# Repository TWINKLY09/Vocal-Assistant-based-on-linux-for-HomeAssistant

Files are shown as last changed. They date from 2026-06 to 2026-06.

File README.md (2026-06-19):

# 🎙️ Voice Assistant — Open Hardware

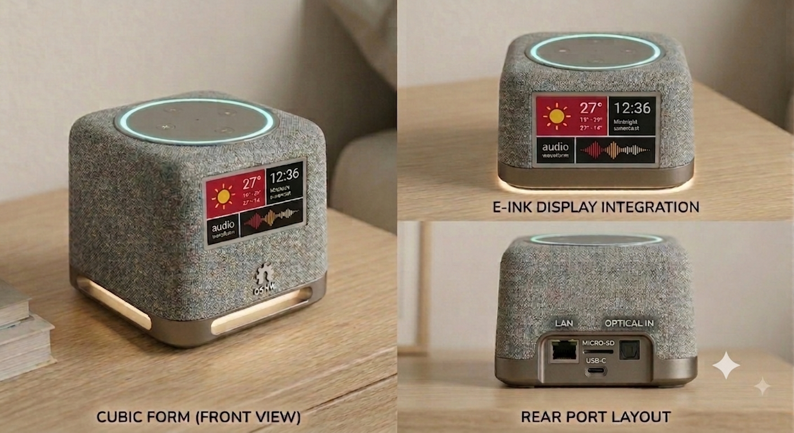
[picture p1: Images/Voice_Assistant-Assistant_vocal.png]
Voice Assistant - Assistant vocal


This image has been generated by gemini

> **⚠️ Work in progress / En cours de développement**
> 
> Hardware is being validated, software is not yet functional end-to-end.
> **3D enclosure files are not yet available** — mechanical design is still in progress.
>
> Le hardware est en cours de validation, le software n'est pas encore fonctionnel de bout en bout.
> **Les fichiers 3D du boîtier ne sont pas encore disponibles** — le design mécanique est en pleine phase de conception.






---

## 🤝 Contributing / Contribuer

**All contributions are welcome**, especially on the software side:
- Linux device tree tuning (I2S, GMAC, SPI)
- Audio pipeline (ALSA / PipeWire, wake-word detection)
- ESP32 firmware (I2C coprocessor, peripheral management)
- Driver integration for sensors (BMI160, LIS2MDL, VL53L0, OPT3001…)
- Any experience with RK3308 / Radxa rCore on mainline kernel

Feel free to open an issue or a pull request. Even feedback or questions are helpful at this stage.

**Toutes les contributions sont les bienvenues**, en particulier côté software :
- Tuning du device tree Linux (I2S, GMAC, SPI)
- Pipeline audio (ALSA / PipeWire, détection de mot de réveil)
- Firmware ESP32 (coprocesseur I2C, gestion des périphériques)
- Intégration des drivers capteurs (BMI160, LIS2MDL, VL53L0, OPT3001…)
- Toute expérience avec RK3308 / Radxa rCore sur kernel mainline

N'hésite pas à ouvrir une issue ou une pull request. Même un retour ou une question est utile à ce stade.

---

## 📸 Photos

> *Photos coming soon — PCB is being assembled.*
> *Photos à venir — le PCB est en cours d'assemblage.*

<!-- Une fois les photos disponibles, les mettre dans le dossier images/ et décommenter : -->

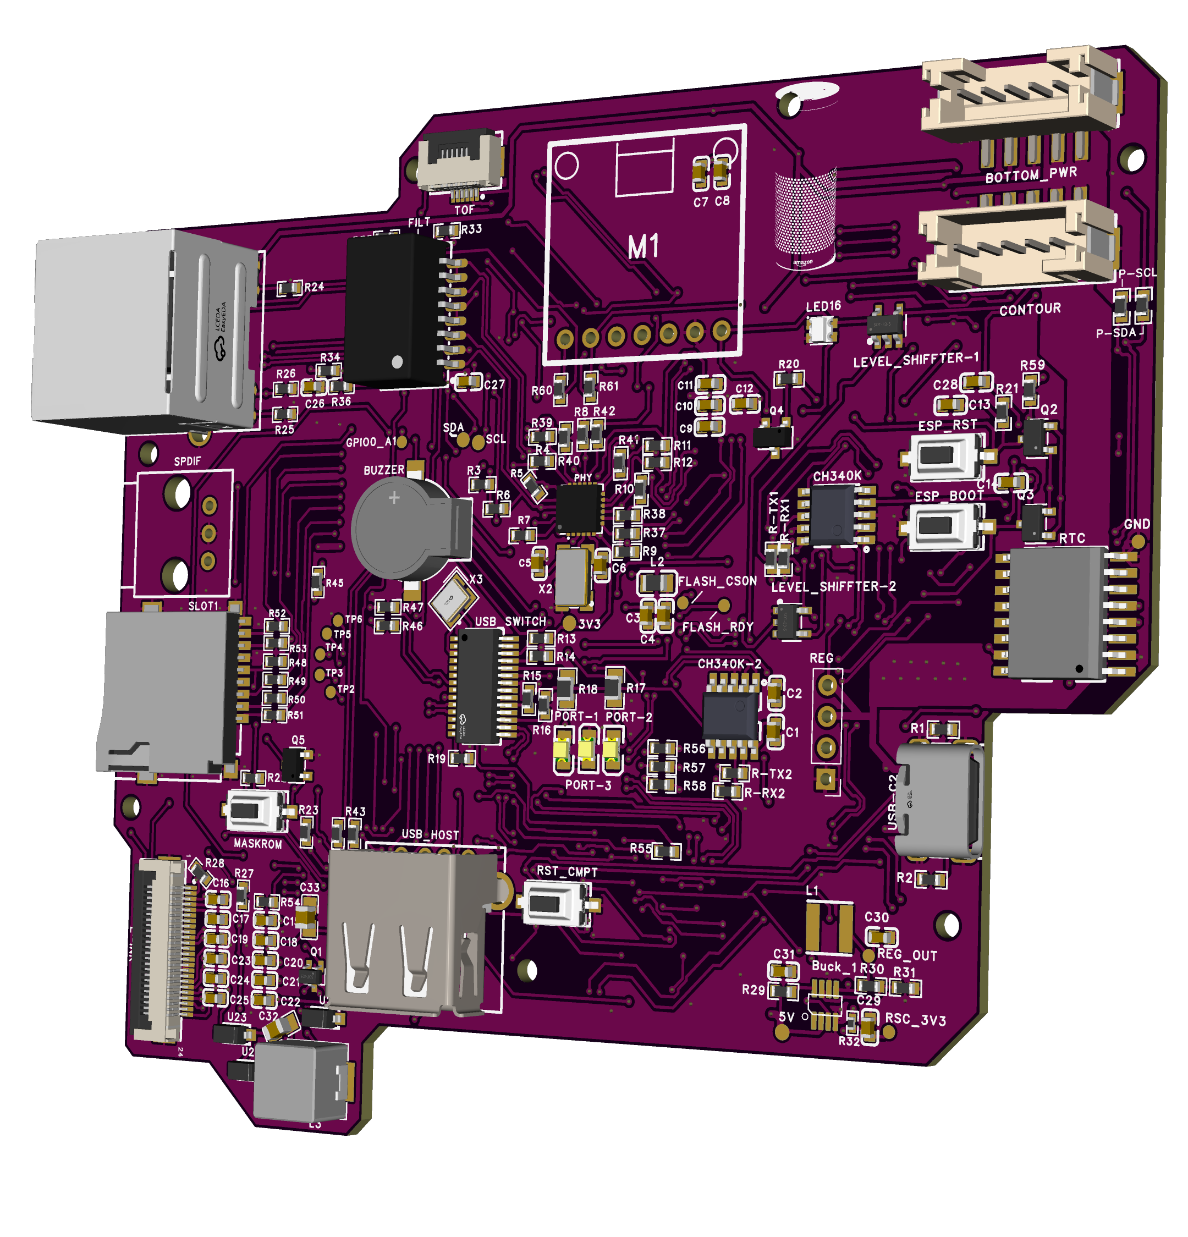
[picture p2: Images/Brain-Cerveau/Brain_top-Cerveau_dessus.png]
PCB Cerveau top

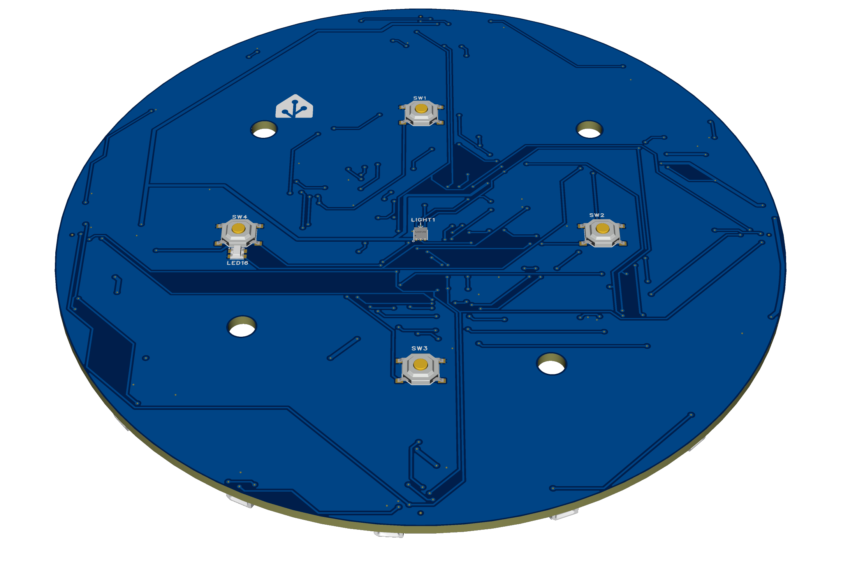
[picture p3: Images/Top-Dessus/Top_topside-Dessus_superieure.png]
PCB Dessus

Stack complet

---

## 🧠 What is this? / C'est quoi ?

This is an **open-hardware embedded voice assistant** built around the **Radxa rCore module (Rockchip RK3308B)**, running Linux on a custom multi-layer PCB stack. The system captures voice through a 4-microphone MEMS array, processes audio in real time under Linux, and delivers audio output via an I2S Class-D amplifier. Network connectivity (Ethernet + WiFi/BT) enables access to cloud services or a local backend.

C'est un **assistant vocal embarqué open hardware** construit autour du module **Radxa rCore (Rockchip RK3308B)**, sous Linux sur un stack de PCB custom multi-couches. Le système capture la voix via 4 microphones MEMS, traite le signal audio en temps réel sous Linux, et restitue la réponse via un ampli DAC I2S. La connectivité réseau (Ethernet + WiFi/BT) permet l'accès à des services cloud ou à un backend local.

---

## 🗂️ Hardware Architecture / Architecture matérielle

```
┌─────────────────────────────────────────────┐
│           PCB Cerveau (main board)           │
│  rCore RK3308B · ESP32 · RTC · USB · ETH    │
└────────┬──────────────┬───────────────┬──────┘
         │ FPC 17P      │ FPC 12P       │ FPC 5P
    ┌────┴────┐    ┌────┴────┐    ┌─────┴────┐
    │  Dessus │    │ Dessous │    │ Contour  │
    │  (Top)  │    │(Bottom) │    │ RGB LEDs │
    └────┬────┘    └─────────┘    └──────────┘
         │ FPC 6P
    ┌────┴────┐
    │  Avant  │
    │ (Front) │
    │   ToF   │
    └─────────┘
```

---

## 🖥️ PCB Cerveau — Main Board

### Compute

| Component | Part | Description |
|---|---|---|
| **SOM** | Radxa rCore (RK3308B) | Quad-core ARM Cortex-A35 @ 1.3GHz, 512MB DDR3, 8GB eMMC |
| **Coprocessor** | ESP32-WROOM-32U-N4 | WiFi 802.11b/g/n + BT 4.2 MCU, connected via I2C1 to RK3308B |

| Composant | Réf. | Description |
|---|---|---|
| **SOM** | Radxa rCore (RK3308B) | Module quad-core ARM Cortex-A35 @ 1.3GHz, 512MB DDR3, 8GB eMMC |
| **Coprocesseur** | ESP32-WROOM-32U-N4 | Microcontrôleur WiFi 802.11b/g/n + BT 4.2, connecté via I2C1 au RK3308B |

### Displays / Afficheurs

| Component | Part | Interface | Description |
|---|---|---|---|
| **eInk 2.9"** | Waveshare 2.9" G | SPI2 | e-Paper display 296×128px, FPC 24P connector, ultra low power |
| **OLED 0.49"** | Wisevision X049-6432TSWPG02-H14 | I2C | OLED display 64×32px (on Bottom PCB) |

| Composant | Réf. | Interface | Description |
|---|---|---|---|
| **eInk 2.9"** | Waveshare 2.9" G | SPI2 | Écran e-paper 296×128px, connecteur FPC 24P, très faible consommation |
| **OLED 0.49"** | Wisevision X049-6432TSWPG02-H14 | I2C | Écran OLED 64×32px (sur PCB Dessous) |

### Network / Connectivité réseau

| Component | Part | Description |
|---|---|---|
| **Ethernet PHY** | Microchip LAN8720A | RMII 10/100Mbps PHY, MDIO addr 0x01, 50MHz REFCLK from SoC, reset GPIO0_B7 |
| **ETH transformer** | PULSE HX1188NL | Integrated magnetic filter, coupled to RJ45 |

| Composant | Réf. | Description |
|---|---|---|
| **PHY Ethernet** | Microchip LAN8720A | PHY RMII 10/100Mbps, adresse MDIO 0x01, REFCLK 50MHz généré par le SoC, reset GPIO0_B7 |
| **Transformateur ETH** | PULSE HX1188NL | Filtre magnétique Ethernet intégré, couplé au RJ45 |

### USB & Serial / USB & Interfaces série

| Component | Part | Description |
|---|---|---|
| **USB-UART #1** | WCH CH340K | USB to UART bridge for ESP32 programming and debug |
| **USB-UART #2** | WCH CH340K | USB to UART bridge for RK3308B Linux console (UART0) |
| **USB Hub** | Terminus FE1.1S | USB 1.1 hub BSOP28 |

| Composant | Réf. | Description |
|---|---|---|
| **USB-UART #1** | WCH CH340K | Pont USB-UART pour programmation et debug de l'ESP32 |
| **USB-UART #2** | WCH CH340K | Pont USB-UART pour console debug Linux du RK3308B (UART0) |
| **USB Hub** | Terminus FE1.1S | Hub USB 1.1 BSOP28 |

### Timekeeping & Power / Temps réel & Alimentation

| Component | Part | Description |
|---|---|---|
| **RTC** | NXP PCF2129T | I2C real-time clock with battery backup, SO-16 |
| **Buck converter** | MP2161 | DC/DC step-down converter TSOT23-8 |
| **Buzzer** | MLT-9032 | SMD piezo buzzer 9×3mm |

| Composant | Réf. | Description |
|---|---|---|
| **RTC** | NXP PCF2129T | Horloge temps réel I2C avec backup batterie, SO-16 |
| **Buck converter** | MP2161 | Convertisseur abaisseur DC/DC TSOT23-8 |
| **Buzzer** | MLT-9032 | Buzzer piézo SMD 9×3mm |

### Discrete actives / Discrets actifs

| Component | Part | Role |
|---|---|---|
| N-MOSFET | BSS138 ×2 | Logic level shifting |
| 3-state buffer | 74AHCT1G125GV ×2 | 5V↔3.3V level shifter |
| P-MOSFET | SI1308EDL | Power switching |
| NPN BJT | MMBT3904 ×2 | Signal driving |
| Schottky diode | MBR0530 ×3 | Protection / rectification |

| Composant | Réf. | Rôle |
|---|---|---|
| MOSFET N | BSS138 ×2 | Adaptation de niveaux logiques |
| Buffer 3 états | 74AHCT1G125GV ×2 | Level shifter 5V↔3.3V |
| MOSFET P | SI1308EDL | Commutation alimentation |
| BJT NPN | MMBT3904 ×2 | Pilotage signaux |
| Diode Schottky | MBR0530 ×3 | Protection / redressement |

### Oscillators / Oscillateurs

| Component | Frequency | Use |
|---|---|---|
| SMD Crystal | 25 MHz | Ethernet PHY reference |
| SMD Crystal | 12 MHz | CH340K reference |

| Composant | Fréquence | Usage |
|---|---|---|
| Quartz SMD | 25 MHz | Référence PHY Ethernet |
| Quartz SMD | 12 MHz | Référence CH340K |

---

## 🔊 PCB Dessus (Top) — Audio & Sensors / Audio & Capteurs

### Audio

| Component | Part | Description |
|---|---|---|
| **MEMS Mic ×4** | Knowles SPH0645LM4H-B-8 | Digital I2S 24-bit MEMS microphones, 4 independent channels (SDI0–SDI3 on I2S0) |
| **DAC Amplifier** | Maxim MAX98357A | Class-D mono I2S amplifier 3.2W, enable via GPIO0_B2 |

| Composant | Réf. | Description |
|---|---|---|
| **Micro MEMS ×4** | Knowles SPH0645LM4H-B-8 | Microphones MEMS numériques I2S 24 bits, 4 canaux indépendants (SDI0–SDI3 sur I2S0) |
| **Ampli DAC** | Maxim MAX98357A | Ampli classe D mono I2S 3.2W, enable via GPIO0_B2 |

### Environmental sensors / Capteurs environnementaux

| Component | Part | Interface | Description |
|---|---|---|---|
| **6-axis IMU** | Bosch BMI160 | I2C/SPI | Accelerometer + gyroscope, addr 0x68 |
| **Magnetometer** | ST LIS2MDLTR | I2C | 3-axis magnetometer, addr 0x1E |
| **Ambient light** | TI OPT3001DNPR | I2C | Calibrated lux sensor, visible spectrum |
| **Temp/Humidity** | TI HDC1080DMBR | I2C | Temperature + relative humidity, addr 0x40 |

| Composant | Réf. | Interface | Description |
|---|---|---|---|
| **IMU 6 axes** | Bosch BMI160 | I2C/SPI | Accéléromètre + gyroscope, adresse 0x68 |
| **Magnétomètre** | ST LIS2MDLTR | I2C | Magnétomètre 3 axes, adresse 0x1E |
| **Lumière ambiante** | TI OPT3001DNPR | I2C | Capteur lux calibré spectre visible |
| **Temp/Humidité** | TI HDC1080DMBR | I2C | Température + humidité relative, adresse 0x40 |

### GPIO & LEDs

| Component | Part | Description |
|---|---|---|
| **I2C GPIO expander** | TI PCA9554DW | 8-bit I2C GPIO expander SOIC-16 |
| **Level shifter** | 74AHCT1G125GV ×2 | 3-state buffer 5V↔3.3V |
| **RGB LED** | Worldsemi WS2812B-2020 ×1 | Addressable RGB LED 2×2mm |
| **RGB LED array** | Worldsemi WS2812C-4020 ×15 | Addressable RGB LEDs 4×2mm |

| Composant | Réf. | Description |
|---|---|---|
| **I2C GPIO expander** | TI PCA9554DW | Expander I2C 8 bits SOIC-16 |
| **Level shifter** | 74AHCT1G125GV ×2 | Buffer 3 états 5V↔3.3V |
| **LED RGB** | Worldsemi WS2812B-2020 ×1 | LED RGB adressable 2×2mm |
| **LED RGB array** | Worldsemi WS2812C-4020 ×15 | LEDs RGB adressables 4×2mm |

---

## 📟 PCB Dessous (Bottom) — Power & Interface

| Component | Part | Interface | Description |
|---|---|---|---|
| **Power monitor** | TI INA260AIPW | I2C | Voltage/current/power measurement TSSOP-16 |
| **I2C GPIO expander** | NXP PCA9536D | I2C | 4-bit I2C GPIO expander SOIC-8 |
| **OLED LDO** | TOREX XC6206P402MR | — | 4.0V dedicated regulator for OLED |
| **P-MOSFET** | FDN338P | — | Power switching |
| **N-MOSFET** | FDN335N | — | Signal switching |

| Composant | Réf. | Interface | Description |
|---|---|---|---|
| **Moniteur puissance** | TI INA260AIPW | I2C | Mesure tension/courant/puissance TSSOP-16 |
| **I2C GPIO expander** | NXP PCA9536D | I2C | Expander I2C 4 bits SOIC-8 |
| **LDO OLED** | TOREX XC6206P402MR | — | Régulateur 4.0V dédié alimentation OLED |
| **MOSFET P** | FDN338P | — | Commutation alimentation |
| **MOSFET N** | FDN335N | — | Commutation signal |

---

## 📡 PCB Avant (Front) — Proximity / Détection de proximité

| Component | Part | Interface | Description |
|---|---|---|---|
| **ToF sensor** | ST VL53L0CXV0DH/1 | I2C | Laser Time-of-Flight rangefinder, 2m range, 12P LGA |

| Composant | Réf. | Interface | Description |
|---|---|---|---|
| **Capteur ToF** | ST VL53L0CXV0DH/1 | I2C | Télémètre laser Time-of-Flight, portée 2m, 12P LGA |

---

## 💡 PCB Contour — RGB Ring / Anneau LED

| Component | Part | Description |
|---|---|---|
| **Addressable RGB LED ×15** | SK6812 | 5×5mm RGB LEDs, decorative / status ring |

| Composant | Réf. | Description |
|---|---|---|
| **LED RGB adressable ×15** | SK6812 | LEDs RGB 5×5mm, anneau décoratif / status |

---

## 🔌 Software interfaces / Interfaces logicielles

| Interface | Bus | Connected to / Périphériques |
|---|---|---|
| I2S0 Master | GPIO2 | MAX98357A (SDO0) + 4× SPH0645 (SDI0–3) |
| SPDIF TX | GPIO0_C1 | Digital audio output / Sortie audio numérique |
| GMAC RMII | GPIO1_B4→C5 | LAN8720A |
| SPI2 | GPIO1_C6/C7/D0/D1 | eInk 2.9" 296×128px |
| I2C1 | GPIO0_B3/B4 | ESP32 |
| I2C2 | GPIO2_A2/A3 | BMI160, LIS2MDL, OPT3001, HDC1080, INA260, PCA9554, PCA9536, VL53L0, OLED 0.49" |
| UART0 | GPIO2_A0/A1 | Linux debug console / Console debug Linux |
| GPIO | GPIO0 divers | LEDs, buttons, MAX98357A enable, PHY reset |

---

## 🗂️ Repository structure / Structure du dépôt

```
├── hardware/
│   └── rk3308-custom-pcb.dts    # Linux device tree overlay
├── bom/
│   ├── BOM_Cerveau.xlsx
│   ├── BOM_Dessus.xlsx
│   ├── BOM_Dessous.xlsx
│   ├── BOM_Avant.xlsx
│   └── BOM_Contour.xlsx
├── images/
│   └── (photos coming soon / photos à venir)
├── LICENSE                       # MIT (software)
├── LICENSE-HARDWARE              # CERN-OHL-P v2 (hardware)
└── README.md
```

---

## 🔧 Software environment / Environnement logiciel

**EN:** Debian Linux image (Radxa Pi S0 base), Linux 5.x BSP Rockchip kernel (modified), ALSA / PipeWire audio stack, custom device tree overlay.

**FR:** Image Debian Linux (base Radxa Pi S0), kernel Linux 5.x BSP Rockchip (modifié), stack audio ALSA / PipeWire, overlay device tree custom.

---

## ⚠️ Development notes / Notes de développement

**EN:**
> Hardware validation in progress. Key points to verify at first boot:
> - SPH0645 1-bit offset (non-standard Philips I2S format)
> - LAN8720A REFCLK direction (`clock_in_out = "output"`)
> - PHY MDIO address (0x01 via PHYAD0/RXER 10kΩ pull-up)
> - I2C addresses: BMI160 0x68 · LIS2MDL 0x1E · OPT3001 configurable · HDC1080 0x40 · INA260 configurable · VL53L0 0x29

**FR:**
> Validation hardware en cours. Points à vérifier au premier boot :
> - Décalage 1 bit SPH0645 (format Philips I2S non standard)
> - Direction REFCLK LAN8720A (`clock_in_out = "output"`)
> - Adresse MDIO PHY (0x01 via PHYAD0/RXER pull-up 10kΩ)
> - Adresses I2C : BMI160 0x68 · LIS2MDL 0x1E · OPT3001 configurable · HDC1080 0x40 · INA260 configurable · VL53L0 0x29

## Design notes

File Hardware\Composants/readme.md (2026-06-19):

## 🔌 Components connected to the Radxa module (excluding passives)

### Brain PCB (directly connected to the rCore SOM)

- ESP32-WROOM-32U-N4 (coprocessor, I2C1)
- LAN8720A (RMII Ethernet PHY)
- PCF2129T (RTC, I2C)
- CH340K ×2 (USB-UART)
- FE1.1S (USB hub)
- HX1188NL (Ethernet transformer)
- MP2161 (buck converter)
- MLT-9032 (buzzer)
- eInk Waveshare 2.9" 296×128px (SPI2)

### Top PCB (via FPC connector to I2C2)

- BMI160 (6-axis IMU)
- LIS2MDLTR (magnetometer)
- OPT3001DNPR (ambient light)
- HDC1080DMBR (temperature/humidity)
- PCA9554DW (8-bit GPIO expander)
- 4× SPH0645LM4H (I2S microphones, not I2C)
- MAX98357A (I2S amplifier, not I2C)

### Bottom PCB (via FPC to I2C2)

- INA260AIPW (power monitor)
- PCA9536D (4-bit GPIO expander)
- OLED 0.49" Wisevision (I2C)

### Front PCB (via FPC to I2C2)

- VL53L0CXV0DH/1 (ToF sensor)

### LEDs (non-I2C, controlled by the ESP32)

- SK6812 ×15 (Contour ring)
- WS2812B/C ×17 (Top ring + status)

Composants reliés au module Radxa (hors passifs)
Basé sur tout ce qu'on a établi ensemble :
Sur PCB Cerveau (directement liés au SOM rCore) :

ESP32-WROOM-32U-N4 (coprocesseur, I2C1)
LAN8720A (PHY Ethernet RMII)
PCF2129T (RTC, I2C)
CH340K ×2 (USB-UART)
FE1.1S (hub USB)
HX1188NL (transfo Ethernet)
MP2161 (buck converter)
MLT-9032 (buzzer)
eInk Waveshare 2.9" 296×128px (SPI2)

Sur PCB Dessus (via connecteur FPC vers I2C2) :

BMI160 (IMU 6 axes)
LIS2MDLTR (magnétomètre)
OPT3001DNPR (lumière ambiante)
HDC1080DMBR (température/humidité)
PCA9554DW (GPIO expander 8 bits)
4× SPH0645LM4H (micros I2S, pas I2C)
MAX98357A (ampli I2S, pas I2C)

Sur PCB Dessous (via FPC vers I2C2) :

INA260AIPW (moniteur puissance)
PCA9536D (GPIO expander 4 bits)
OLED 0.49" Wisevision (I2C)

Sur PCB Avant (via FPC vers I2C2) :

VL53L0CXV0DH/1 (capteur ToF)

LEDs (non-I2C, contrôlées par l'ESP32) :

SK6812 ×15 (Contour)
WS2812B/C ×17 (Dessus + status)

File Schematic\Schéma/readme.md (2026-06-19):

These PDFs are made available to make reviewing the different schematics and understanding how the device works easely. They are also to show-off the product and it's design. 

Ces fichiers pdf sont rendu disspo pour rendre la revue des schémas des différentes pièces et pour conprendre le fonctionnement de l'apareil plus facilement. Ils servent aussi à montrer le produit et son design.

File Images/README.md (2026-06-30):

This folder contains images of the different PCBs for reference.
The photo of the product has been generated using Google gemini.

Ce dossier contient des images des différents circuits pour référence.
La photo du produit a été généré par Google gemini.

  VOICE ASSISTANT - ASSISTANT VOCAL
Voice Assistant - Assistant vocal

Brain_bottom-Cerveau_dessus
Brain top - Cerveau dessus

Brain_bottom-Cerveau_dessous
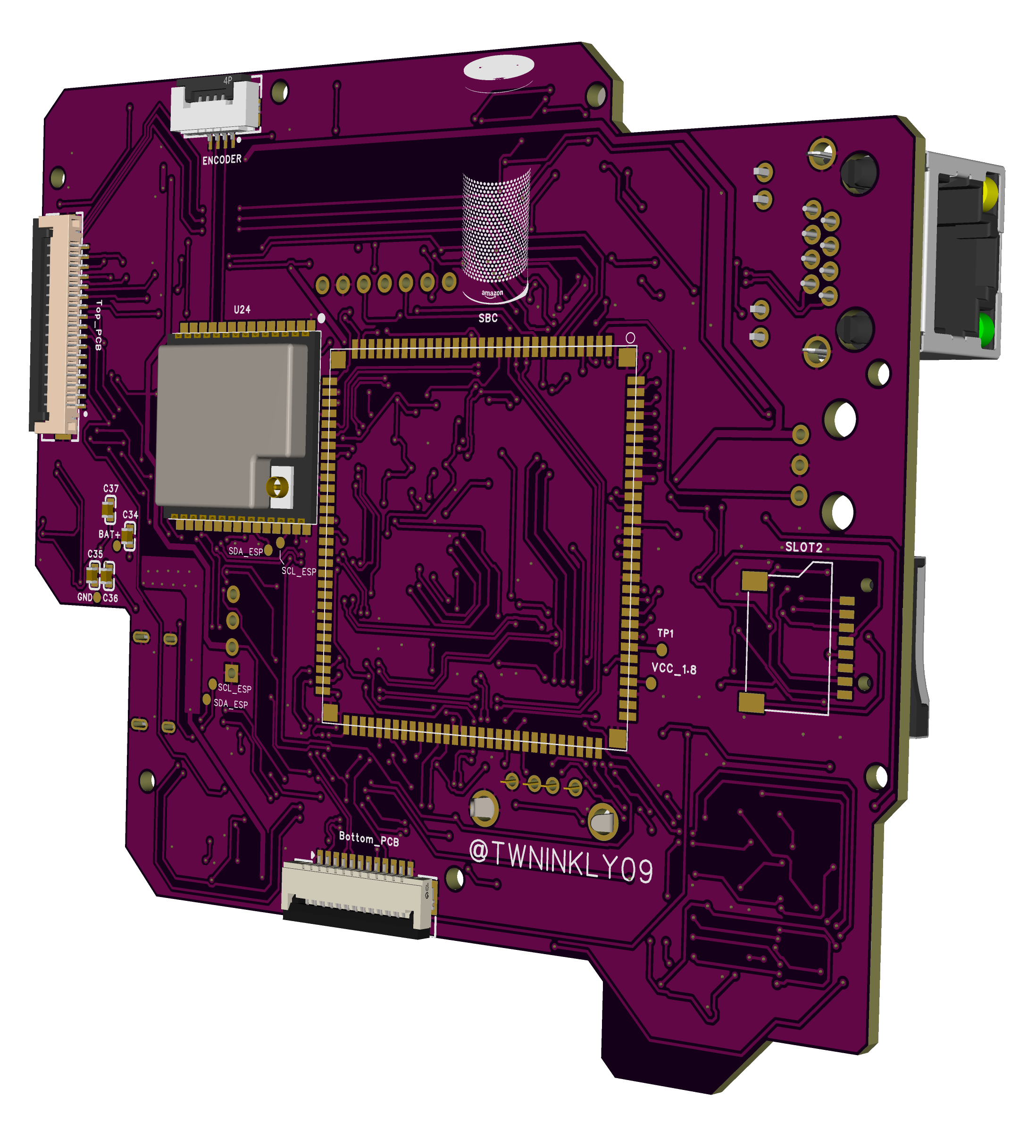
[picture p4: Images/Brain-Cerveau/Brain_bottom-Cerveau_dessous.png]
Brain bottom - Cerveau dessous


Brain_bottom_connectors
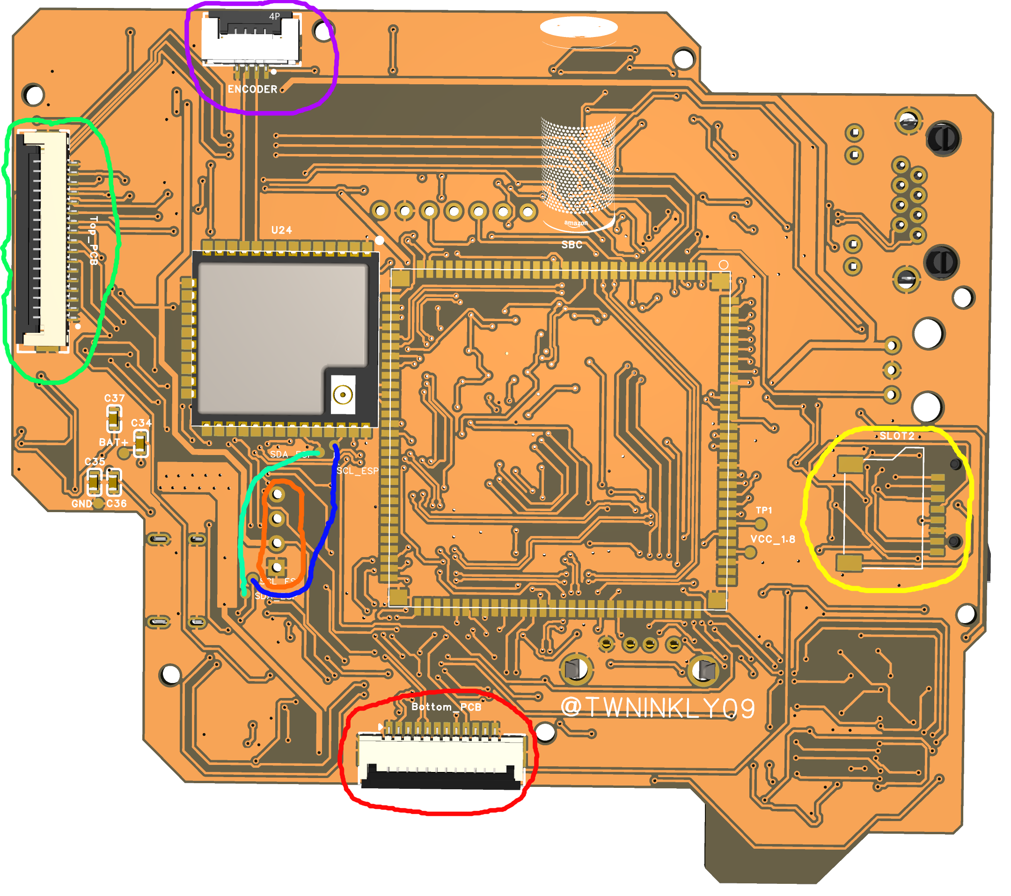
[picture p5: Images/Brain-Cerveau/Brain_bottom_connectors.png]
Brain bottom connectors


Brain_front_connectors
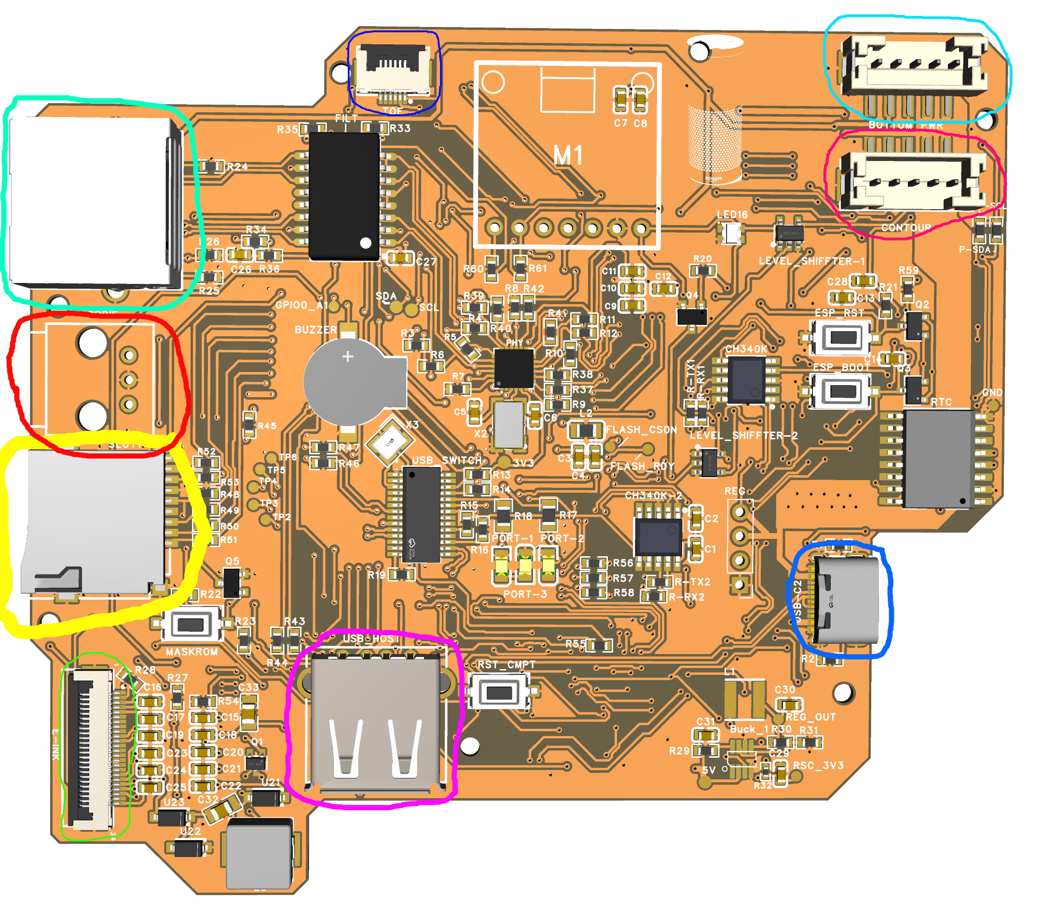
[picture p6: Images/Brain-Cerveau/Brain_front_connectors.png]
Brain front connectors


Bottom_top-Bas_dessus
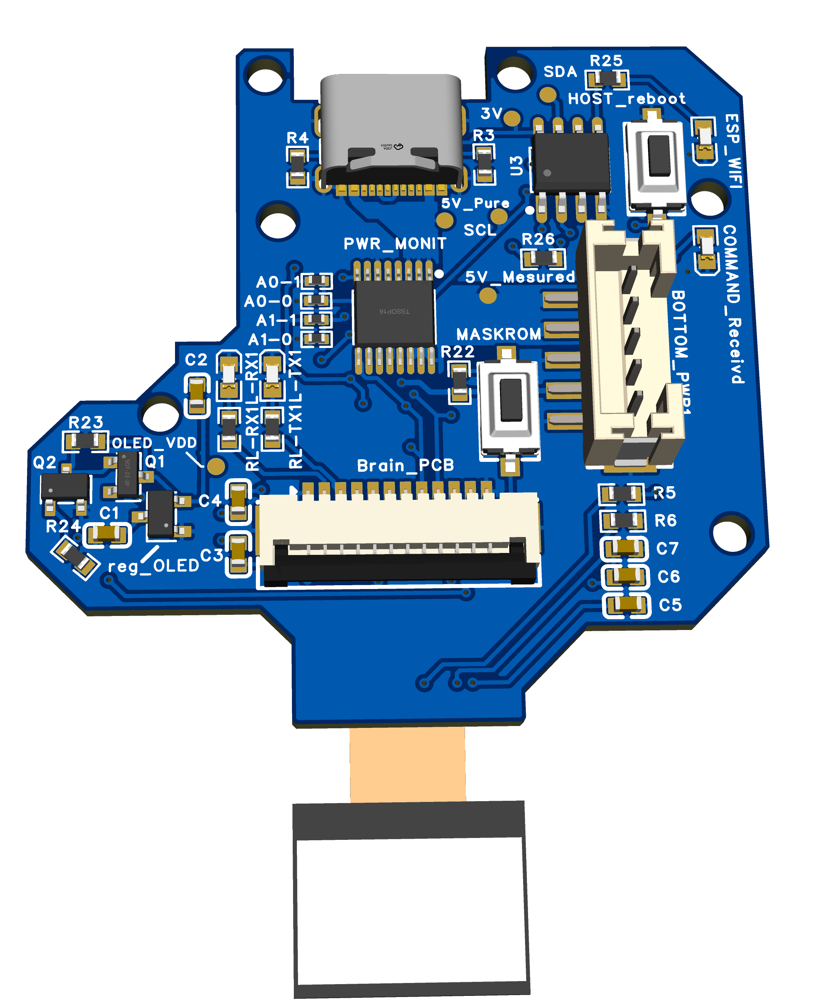
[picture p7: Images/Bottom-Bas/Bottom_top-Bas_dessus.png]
Bottom top - Bas dessus


Bottom_underside-Bas_dessous
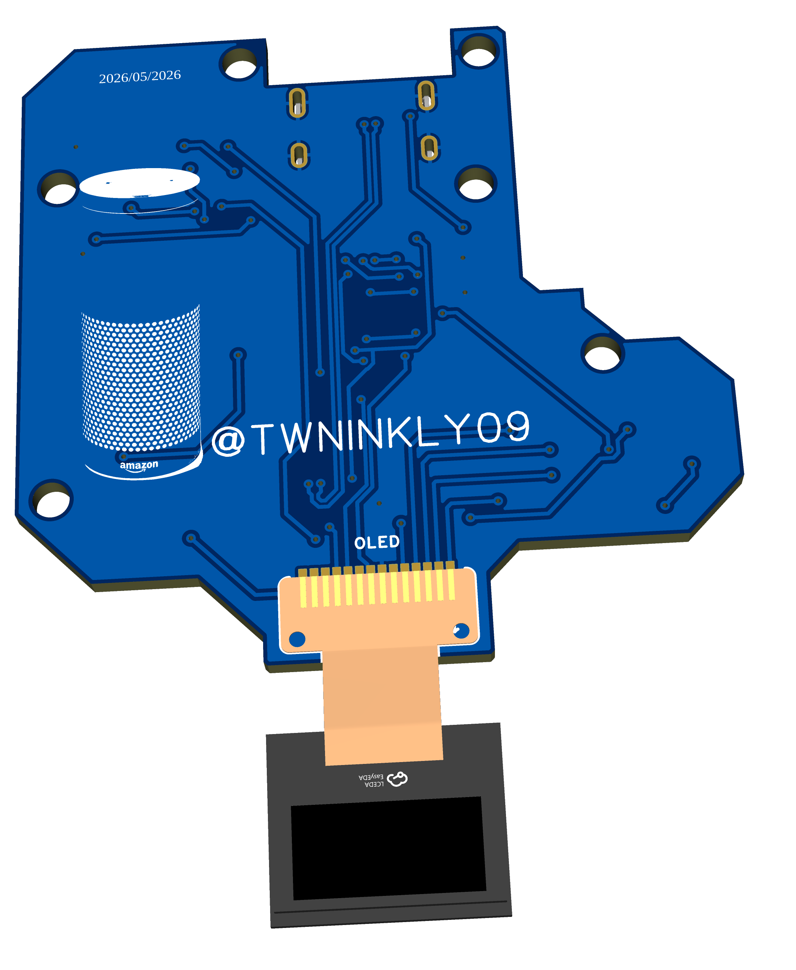
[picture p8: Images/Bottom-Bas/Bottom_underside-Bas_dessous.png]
Bottom underside - Bas dessous


Top_topside-Dessus_superieure
Top topside - Dessus superieure

Top_underside-Dessous_inferieure
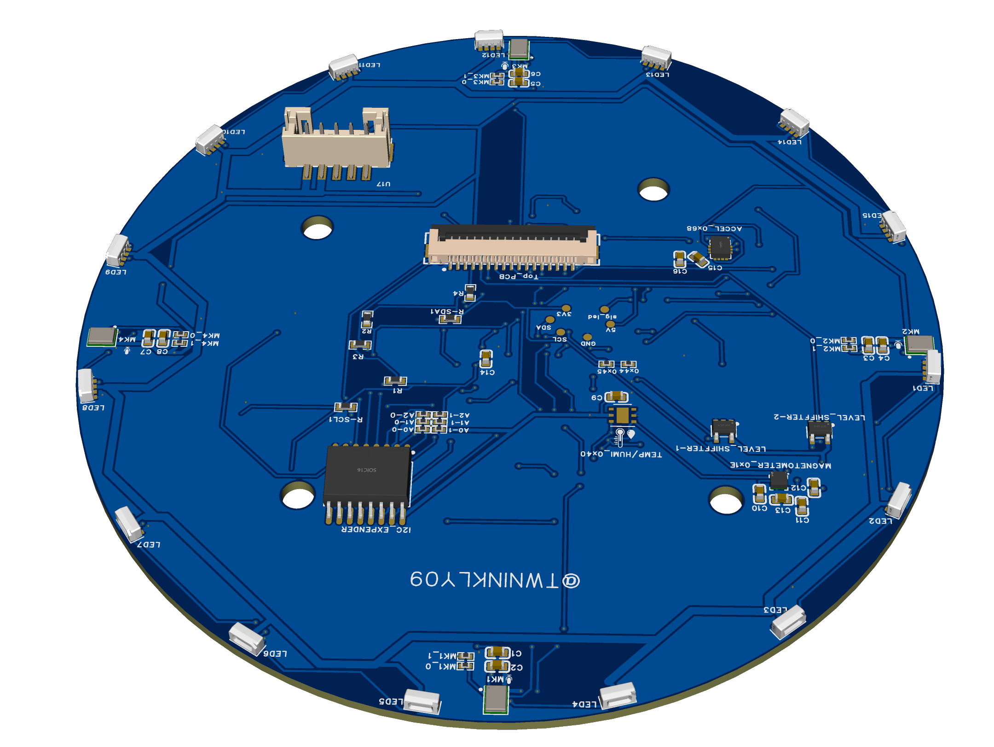
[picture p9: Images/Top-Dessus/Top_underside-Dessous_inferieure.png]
Top underside - Dessus inferieure


Contour_bottom-dessus
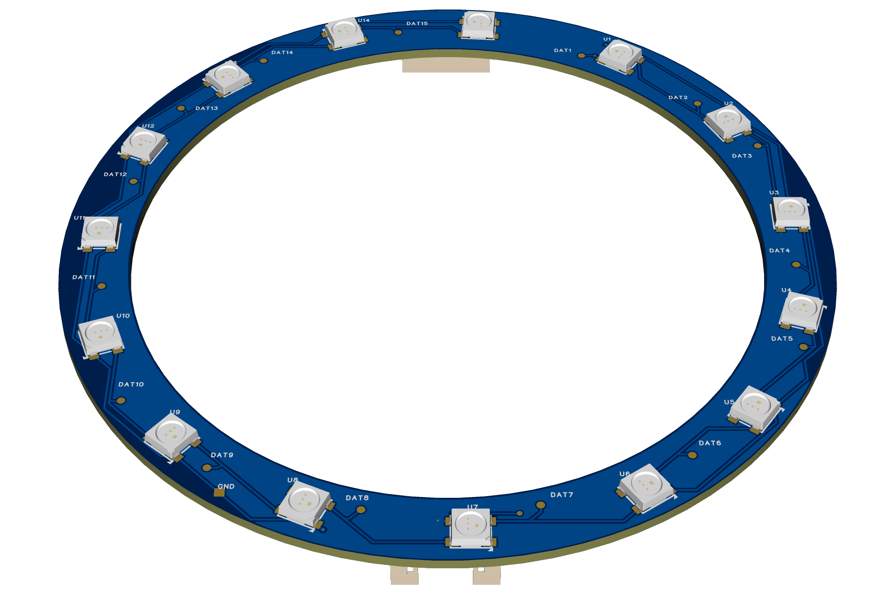
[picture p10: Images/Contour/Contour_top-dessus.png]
Contour top - dessus


Contour_-dessous
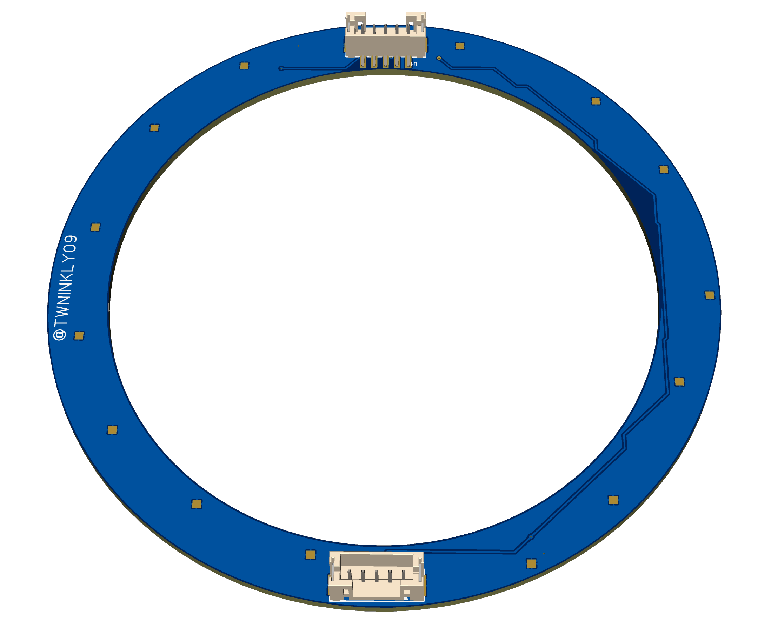
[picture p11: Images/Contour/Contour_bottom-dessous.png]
Contour bottom - dessous


Front_bottom-Face_dessus
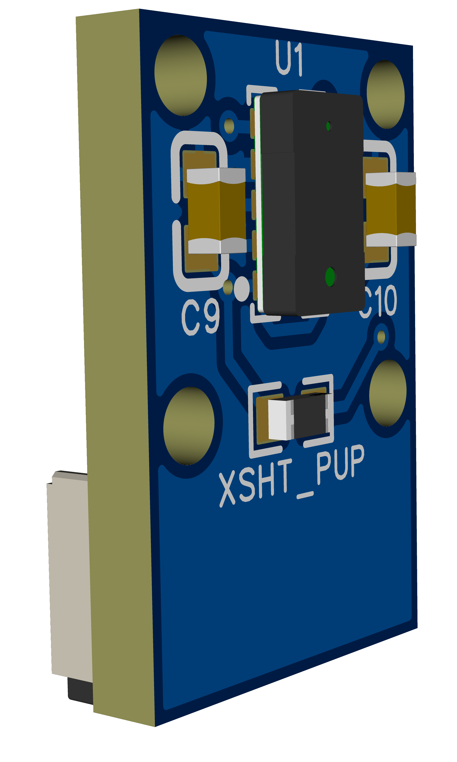
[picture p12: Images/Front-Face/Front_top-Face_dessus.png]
Front top - Face dessus


Front_bottom-Face_dessous
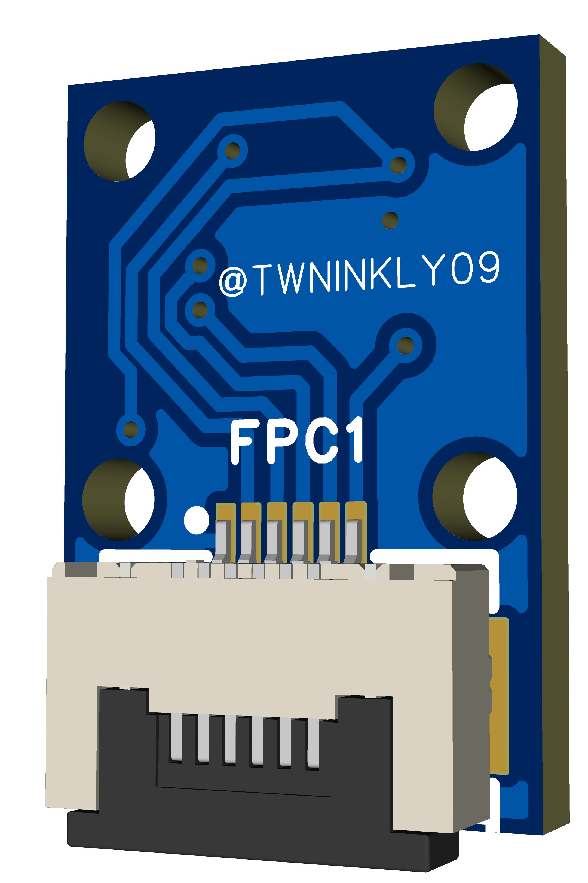
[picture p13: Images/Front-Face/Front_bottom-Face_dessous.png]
Front bottom - Face dessous


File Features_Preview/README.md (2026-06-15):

The GIFs files shows how every led animations and how the device is supposed to behave.
Ces fichiers GIF montrent à quoi sont supposer ressembler chaques animations sur les led et comment se comporte l'apareil dans chaque situation.. 

When booting. / Pendant le démarrage.

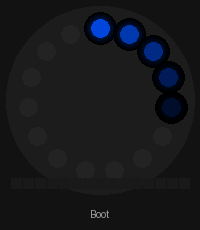
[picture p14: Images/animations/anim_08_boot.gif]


When muted. / Quand les micros sont désactivés.

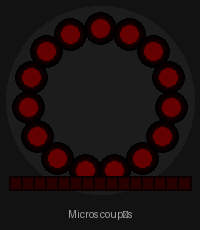
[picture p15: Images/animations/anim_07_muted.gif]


When an error occured. / Quand une erreur est survenue.

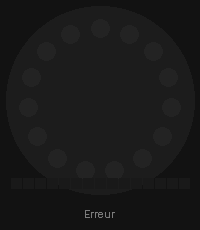
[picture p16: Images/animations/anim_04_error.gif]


While waiting for wake word. / En attente du mot-déclencheur.

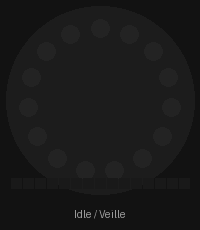
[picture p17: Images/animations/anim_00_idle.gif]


While in do-no-disturb mode. / En mode ne-pas-déranger.

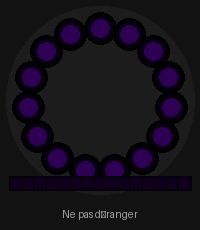
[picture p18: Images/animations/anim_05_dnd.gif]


When it activates. / Quand il est déclenché.

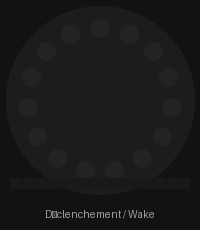
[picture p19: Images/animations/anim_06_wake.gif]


When listening. / Quand il écoute.

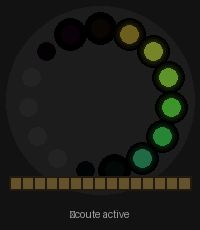
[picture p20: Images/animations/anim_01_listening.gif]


When processing. / En réflexion.

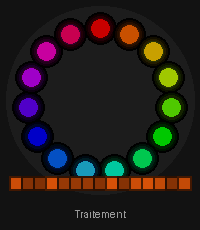
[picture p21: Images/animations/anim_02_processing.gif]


When responding. / Quand il répond.

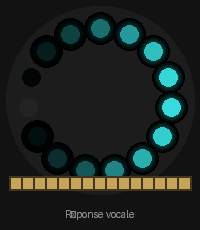
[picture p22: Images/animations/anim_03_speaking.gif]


These ones shows what status the device is in if we look at the status led on the brain-PCB. -- Ceux là montrent dans quel état l'apareil est actuellement si on se fie à la led d'état sur le pcb du cerveau.

When the ESP32 is booting. / Quand l'ESP32 est en train de démarrer.

Démonstration

When the ESP32 is busy. / Quand l'ESP32 est occupé.

Démonstration

When the ESP32 is ready. / Quand l'ESP32 est prêt.

Démonstration

When the mics are muted. / Quand les micros sont coupés.

Démonstration

When the mics are on. / Quand les micros sont actifs.

Démonstration

When the ESP32 encountered an error. / Quand l'ESP32 à rencontré une erreur.

Démonstration

And for now that's all the animations programmed but I'm open to hear your ideas for future animations or functions. / Pour l'instant ce sont toutes les animations programmées mais je suis ouvert à vous idées pour de futures animations ou des fonctions.

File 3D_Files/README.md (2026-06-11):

These files are made available to help people to create a shell for the device.
Please note that the silkscreen may not be up to date on these 3d files.
Most of the files are in step format but the ones that aren't was because ther were too big >20MByte.

Ces fichier sont rendus publiques pour permettre au personnes de créer un boîtier pour l'apareil.
Veilliez noter que la sérigraphie n'est peut être pas à jour sur ces fichiers 3D
La plupart des fichiers sont en format .step mais ce qui ne le sont pas , c'est car leur taille était supérieure à 20Moctet.

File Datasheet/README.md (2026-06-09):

These files are made avilable for designing a pcb or to get information about the different components and ICs.
They are in no way my files and all the copyrights andd IPs goes to their respective owners/companies.

Ces fichiers sont rendus accessible publiquement pour designer un pcb ou pour obtenir des infos à propos des composants.
Ce ne sont en aucun cas mes fichiers et tout Copyright/Propriété_Intellectuelle vont à leur propriétaires respectifs.

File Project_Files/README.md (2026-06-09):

These files are made available for people to make modification to the pcb and make it better.

Ces fichiers sont à votre disposition pour que vous puissiez modifier le circuit de votre côté ou l'améliorer.

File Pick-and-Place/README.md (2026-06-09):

These files are if you want a pcb manufacturer to assemble this design but it may be expensive.

Ces fichier servent à ceux qui veulent faire assembler le circuit par un fabricant.

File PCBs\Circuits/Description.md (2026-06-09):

These files are to locate and help people to assemble and solder the different PCBs.

Ces fichiers sont la pour aider les personnes à assembler et souder les différents circuits.

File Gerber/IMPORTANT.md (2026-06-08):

Warning!!! 
There is a mistake I can't correct on the brainpcb that requires 2 wires to connect 4 i²C pads on the same side.
This bodge wire is unavoidable andd essential for the proper fonction of the device and because there is a serious lack of space in the 2 layers of the pcb.

Attention!!!
Il y a une erreur incorrectible sur le circuit du cerveau, il faut souder 2 fils sur les pads apropriés pour restaurer la connexion i2c.
Cette/Ce réparation/bricolage est essentiel au bon fonctionnement de l'apareil et est du à un manque de place dans les 2 couches du pcb.

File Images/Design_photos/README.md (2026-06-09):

These files are a collection of Images of the design process and parts dimmensions.

Ces fichiers sont des images du processus de conception et des dimmensions des pièces.

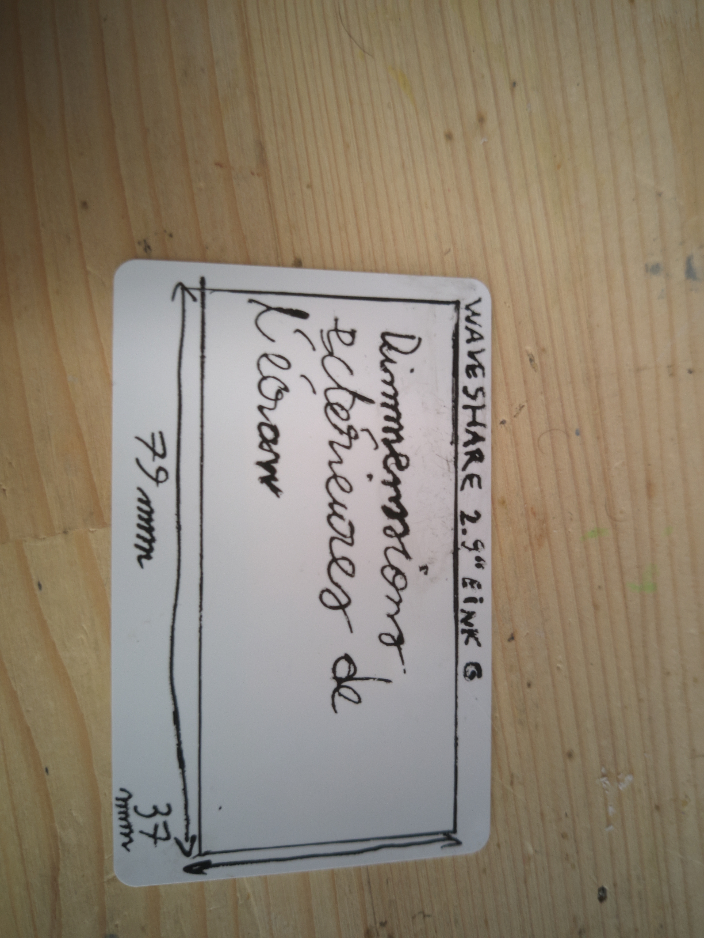
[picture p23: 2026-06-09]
Images/Design_photos/Eink-size_outside_dimmensions_reference.jpg

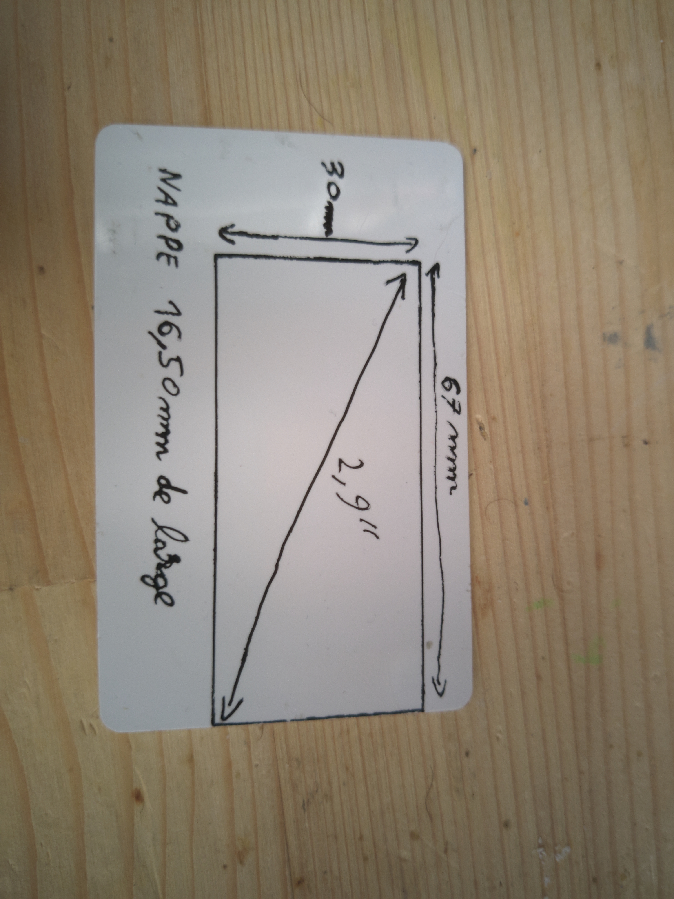
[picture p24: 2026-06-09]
Images/Design_photos/Eink-size_display-area_dimmensions_reference.jpg

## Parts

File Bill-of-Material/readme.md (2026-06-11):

This folder contains the list of all the components you need to assemble every pcb.
Ce dossier contient une liste de tous les composants nécessaires pour assembler chaque circuits.

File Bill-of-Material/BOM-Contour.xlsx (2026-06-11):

No. | Quantity | Comment | Designator | Footprint | Value | Manufacturer Part | Manufacturer | Supplier Part | Supplier
1 | 2 | B5B-PH-SM4-TB(LF)(SN) | U17,U18 | CONN-SMD_5P-P2.00_B6B-PH-SM4-TB-LF-SN |  | B5B-PH-SM4-TB(LF)(SN) | JST | C265085 | LCSC
2 | 15 | SK6812 | U1,U2,U3,U4,U5,U6,U7,U8,U9,U10,U11,U12,U13,U14,U15 | LED-SMD_4P-L5.0-W5.0-LS5.4-TL-1 |  | SK6812 | 欧思科光电 | C5378720 | LCSC
3 | 17 | Test-Point | 5V,DAT1,DAT2,DAT3,DAT4,DAT5,DAT6,DAT7,DAT8,DAT9,DAT10,DAT11,DAT12,DAT13,DAT14,DAT15,GND | Test-Point-0.5mm

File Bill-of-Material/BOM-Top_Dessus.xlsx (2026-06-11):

No. | Quantity | Comment | Designator | Footprint | Value | Manufacturer Part | Manufacturer | Supplier Part | Supplier
1 | 1 | 10uF | C13 | C0603 | 10uF | CL10A106MQ8NNNC | SAMSUNG(三星) | C1691 | LCSC
2 | 1 | 100nF | C14 | C0603 | 100nF | CC0603KRX7R5BB104 | YAGEO(国巨) | C5445386 | LCSC
3 | 4 | 100nF | C11,C12,C15,C16 | C0603 | 100nF | CC0603KRX7R9BB104 | YAGEO(国巨) | C14663 | LCSC
4 | 5 | 100nF=0.1uF | C2,C4,C6,C8,C9 | C0603 | 100nF=0.1uF | CC0603KRX7R9BB104 | YAGEO(国巨) |  | LCSC
5 | 4 | 200pF | C1,C3,C5,C7 | C0603 | 200pF | CC0603KRX7R9BB201 | YAGEO(国巨) | C107080 | LCSC
6 | 1 | 220nF | C10 | C0603 | 220nF | CL10B224KB8NNNC | SAMSUNG(三星) | C64705 | LCSC
7 | 1 | B5B-PH-SM4-TB(LF)(SN) | U17 | CONN-SMD_5P-P2.00_B6B-PH-SM4-TB-LF-SN |  | B5B-PH-SM4-TB(LF)(SN) | JST | C265085 | LCSC
8 | 1 | ZX-1.0FPC-2H-QFX17P | Top_PCB | FPC-SMD_17P-P1.00_ZX-1.0FPC-2H-QFX17P |  | ZX-1.0FPC-2H-QFX17P | Megastar(兆星) | C19191208 | LCSC
9 | 1 | WS2812B-2020 | LED16 | LED-SMD_4P-L2.0-W2.0-TL_WS2812B-2020 |  | WS2812B-2020 | worldsemi | C965555 | LCSC
10 | 15 | WS2812C-4020 | LED1,LED2,LED3,LED4,LED5,LED6,LED7,LED8,LED9,LED10,LED11,LED12,LED13,LED14,LED15 | LED-SMD_4P-L4.0-W1.7-R |  | WS2812C-4020 | worldsemi | C4154870 | LCSC
11 | 1 | BMI160 | ACCEL_0x68 | LGA-14_L3.0-W2.5-P0.50-BL |  | BMI160 | Bosch(博世) | C94021 | LCSC
12 | 4 | SPH0645LM4H-B-8 | MK1,MK2,MK3,MK4 | MIC-SMD_6P-L3.5-W2.7-P0.90-BL |  | SPH0645LM4H-B-8 | Knowles(楼氏) | C19190864 | LCSC
13 | 1 | Sensor_Humidity_HDC1080 | TEMP/HUMI_0x40 | Package_SON:Texas_PWSON-N6 | HDC1080DMBR
14 | 16 | 0Ω | 0x44,0x45,A0-0,A0-1,A1-0,A1-1,A2-0,A2-1,MK1_0,MK1_1,MK2_0,MK2_1,MK3_0,MK3_1,MK4_0,MK4_1 | R0402 | 0Ω | FRC0402P000 TS | FOJAN(富捷) | C2906877 | LCSC
15 | 2 | 4.7kΩ | R-SCL1,R-SDA1 | R0603 | 4.7kΩ | RC0603FR-074K7L | YAGEO(国巨) | C99782 | LCSC
16 | 4 | 10kΩ | R1,R2,R3,R4 | R0603 | 10kΩ | 0603WAF1002T5E | UNI-ROYAL(厚声) | C25804 | LCSC
17 | 1 | PCA9554DW | I2C_EXPENDER | SOIC-16_L10.3-W7.5-P1.27-LS10.3-BL |  | PCA9554DW | TI(德州仪器) | C1542509 | LCSC
18 | 2 | 74AHCT1G125GV | LEVEL_SHIFFTER-1,LEVEL_SHIFFTER-2 | SOT-23-5_L3.0-W1.7-P0.95-LS2.8-BL |  | 74AHCT1G125GV | MDD(辰达半导体) | C52140417 | LCSC
19 | 4 | TS-1187A-B-A-B | SW1,SW2,SW3,SW4 | SW-SMD_4P-L5.1-W5.1-P3.70-LS6.5-TL_H1.5 |  | TS-1187A-B-A-B | XKB Connection(中国星坤) | C318884 | LCSC
20 | 1 | sig_led | sig_led | Test-Point-0.5mm
21 | 5 | Test-Point | 3V3,5V,GND,SCL,SDA | Test-Point-0.5mm
22 | 1 | OPT3001DNPR | LIGHT1 | USON6_L2.1-W2.1-P0.65-BL-EP |  | OPT3001DNPR | TI(德州仪器) | C90462 | LCSC
23 | 1 | LIS2MDLTR | MAGNETOMETER_0x1E | VLGA-12_L2.0-W2.0-P0.50-BL |  | LIS2MDLTR | ST(意法半导体) | C919695 | LCSC

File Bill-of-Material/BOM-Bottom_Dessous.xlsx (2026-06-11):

No. | Quantity | Comment | Designator | Footprint | Value | Manufacturer Part | Manufacturer | Supplier Part | Supplier
1 | 4 | 1uF | C1,C2,C3,C4 | C0603 | 1uF | CL10B105KB8NQNC | SAMSUNG(三星) | C5199872 | LCSC
2 | 1 | 2.2uF | C5 | C0603 | 2.2uF | CL10A225KO8NNNC | SAMSUNG(三星) | C23630 | LCSC
3 | 1 | 4.7uF | C6 | C0603 | 4.7uF | CL10A475KP8NNNC | SAMSUNG(三星) | C1705 | LCSC
4 | 1 | 100nF=0.1uF | C7 | C0603 | 100nF=0.1uF | CC0603KRX7R9BB104 | YAGEO(国巨) |  | LCSC
5 | 1 | B5B-PH-SM4-TB(LF)(SN) | BOTTOM_PWR1 | CONN-SMD_5P-P2.00_B6B-PH-SM4-TB-LF-SN |  | B5B-PH-SM4-TB(LF)(SN) | JST | C265085 | LCSC
6 | 1 | FPC-1.0FX-12PWBH20 | Brain_PCB | FPC-SMD_12P-P1.00_XUNPU_FPC-1.0FX-12PWBH20 |  | FPC-1.0FX-12PWBH20 | XUNPU(讯普) | C3446098 | LCSC
7 | 4 | YLED0603O | COMMAND_Receivd,ESP_WIFI,L-RX1,L-TX1 | LED0603-FD |  | YLED0603O | YONGYUTAI(永裕泰) | C19273153 | LCSC
8 | 1 | X049-6432TSWPG02-H14 | OLED1 | OLED-SMD_X049-6432TSWPG02-H14 |  | X049-6432TSWPG02-H14 | Wisevision(新智景) | C18723009 | LCSC
9 | 4 | 0Ω | A0-0,A0-1,A1-0,A1-1 | R0402 | 0Ω | FRC0402P000 TS | FOJAN(富捷) | C2906877 | LCSC
10 | 2 | 10kΩ | R5,R22 | R0603 | 10kΩ | FRC0603J103 TS | FOJAN(富捷) | C2930027 | LCSC
11 | 2 | 47kΩ | R23,R24 | R0603 | 47kΩ | FRC0603F4702TS | FOJAN(富捷) | C2907042 | LCSC
12 | 2 | 150Ω | RL-RX1,RL-TX1 | R0603 | 150Ω | FRC0603J151 TS | FOJAN(富捷) | C2907103 | LCSC
13 | 2 | 330Ω | R25,R26 | R0603 | 330Ω | FRC0603J331 TS | FOJAN(富捷) | C2907152 | LCSC
14 | 1 | 560kΩ | R6 | R0603 | 560kΩ | RC0603FR-07560KL | YAGEO(国巨) | C137699 | LCSC
15 | 2 | 5.1kΩ | R3,R4 | R0603_1 | 5.1kΩ | 0603WAF5101T5E | UNI-ROYAL(厚声) | C23186 | LCSC
16 | 1 | PCA9536D | U3 | SOIC-8_L4.9-W3.9-P1.27-LS6.0-BL |  | PCA9536D | NXP(恩智浦) | C129522 | LCSC
17 | 1 | FDN338P | Q1 | SOT-23-3_L2.9-W1.3-P1.90-LS2.4-BR |  | FDN338P | ElecSuper(静芯) | C22363749 | LCSC
18 | 1 | XC6206P402MR | reg_OLED | SOT-23-3_L2.9-W1.6-P1.90-LS2.8-BR |  | XC6206P402MR | TOREX(特瑞仕) | C484266 | LCSC
19 | 1 | FDN335N | Q2 | SOT-23-3_L3.0-W1.7-P0.95-LS2.9-BR |  | FDN335N | onsemi(安森美) | C241804 | LCSC
20 | 2 | HX 3x6x2.5A-2.5N | HOST_reboot,MASKROM | SW-SMD_HX-TS-1101-C-W |  | HX 3x6x2.5A-2.5N | hanxia(韩下) | C36498960 | LCSC
21 | 6 | Test-Point | 3V,5V_Mesured,5V_Pure,OLED_VDD,SCL,SDA | Test-Point-0.5mm
22 | 1 | INA260AIPW | PWR_MONIT | TSSOP-16_L5.0-W4.4-P0.65-LS6.4-BL |  | INA260AIPW | TI(德州仪器) | C181331 | LCSC
23 | 1 | UC.01.51-11-0017,typec | USB-C1 | TYPE-C-SMD_UC.01.51-11-0017 |  | UC.01.51-11-0017,typec |  | C9900066641 | LCSC

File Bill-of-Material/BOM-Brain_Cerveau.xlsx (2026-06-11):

No. | Quantity | Comment | Designator | Footprint | Value | Manufacturer Part | Manufacturer | Supplier Part | Supplier
1 | 1 | MLT-9032 | BUZZER | BUZ-SMD_MLT-9032 |  | MLT-9032 | 华能 | C194480 | LCSC
2 | 1 | 1nF | C26 | C0603 | 1nF | CL10B102KB8NNNC | SAMSUNG(三星) | C1588 | LCSC
3 | 2 | 1uF | C16,C17 | C0603 | 1uF | 0603X105K100NT | FH(风华) | C111590 | LCSC
4 | 1 | 1uF | C12 | C0603 | 1uF | CGA0603X5R105K500JT | HRE(芯声) | C6119852 | LCSC
5 | 11 | 1uF | C3,C4,C7,C8,C19,C20,C21,C22,C23,C24,C25 | C0603 | 1uF | CL10B105KB8NQNC | SAMSUNG(三星) | C5199872 | LCSC
6 | 1 | 6.8uF | C36 | C0603 | 6.8uF | C1608X5R1A685KT000E | TDK | C338096 | LCSC
7 | 1 | 10nF | C27 | C0603 | 10nF | FCC0603B103K500CT | FOJAN(富捷) | C5137477 | LCSC
8 | 2 | 10uF | C30,C31 | C0603 | 10uF | CL10A106KP8NNNC | SAMSUNG(三星) | C19702 | LCSC
9 | 2 | 22pF | C5,C6 | C0603 | 22pF | CC0603JRNPO9BN220 | YAGEO(国巨) | C105620 | LCSC
10 | 1 | 22uF | C9 | C0603 | 22uF | CL10A226MQ8NRNC | SAMSUNG(三星) | C59461 | LCSC
11 | 1 | 100nF | C18 | C0603 | 100nF | CC0603KRX7R6BB104 | YAGEO(国巨) | C519438 | LCSC
12 | 2 | 100nF | C1,C29 | C0603 | 100nF | CC0603KRX7R9BB104 | YAGEO(国巨) | C14663 | LCSC
13 | 4 | 100nF | C10,C11,C13,C14 | C0603 | 100nF | CGA0603X7R104K500JT | HRE(芯声) | C6119867 | LCSC
14 | 3 | 100nF | C34,C35,C37 | C0603 | 100nF | GRM188R71H104KA93D | muRata(村田) | C77055 | LCSC
15 | 1 | 100nF | C15 | C0603 | 100nF | TCC0603X7R104K500CT | CCTC(三环) | C282519 | LCSC
16 | 2 | 100nF=0.1uF | C2,C28 | C0603 | 100nF=0.1uF | CC0603KRX7R9BB104 | YAGEO(国巨) |  | LCSC
17 | 2 | 4.7uF | C32,C33 | C0805 | 4.7uF | CL21A475KBQNNNE | SAMSUNG(三星) | C98192 | LCSC
18 | 2 | B5B-PH-SM4-TB(LF)(SN) | BOTTOM_PWR,CONTOUR | CONN-SMD_5P-P2.00_B6B-PH-SM4-TB-LF-SN |  | B5B-PH-SM4-TB(LF)(SN) | JST | C265085 | LCSC
19 | 1 | DLR2180 | SPDIF | CONN-TH_DLR2180_1 |  | DLR2180 |  | C9900172794 | LCSC
20 | 1 | Connector_Conn_01x04_Male | REG | Connector_PinHeader_2.54mm:PinHeader_1x04_P2.54mm_Vertical | TLV62569_3v3BuckConverterBreakout
21 | 1 | 12MHz | X3 | CRYSTAL-SMD_4P-L3.2-W2.5-BL | 12MHz | X322512MSB4SI | YXC(扬兴晶振) | C9002 | LCSC
22 | 1 | 25MHz | X2 | CRYSTAL-SMD_4P-L5.0-W3.2-BL | 25MHz | SX5B25.000F2020F30 | SCTF(星通时频) | C2901637 | LCSC
23 | 2 | CH340K | CH340K,CH340K-2 | ESOP-10_L4.9-W3.9-P1.00-LS6.2-BL-EP |  | CH340K | WCH(南京沁恒) | C968586 | LCSC
24 | 1 | AFA01-S04FCA-00 | ENCODER | FPC-SMD_4P-P1.00_JS_AFA01-S04FCA-00 |  | AFA01-S04FCA-00 | JS(钜硕电子) | C262752 | LCSC
25 | 1 | FPC-05F-6PH20 | TOF | FPC-SMD_6P-P0.50_XUNPU_FPC-05F-6PH20 |  | FPC-05F-6PH20 | XUNPU(讯普) | C2856796 | LCSC
26 | 1 | FPC-1.0FX-12PWBH20 | Bottom_PCB | FPC-SMD_12P-P1.00_XUNPU_FPC-1.0FX-12PWBH20 |  | FPC-1.0FX-12PWBH20 | XUNPU(讯普) | C3446098 | LCSC
27 | 1 | ZX-1.0FPC-2H-QFX17P | Top_PCB | FPC-SMD_17P-P1.00_ZX-1.0FPC-2H-QFX17P |  | ZX-1.0FPC-2H-QFX17P | Megastar(兆星) | C19191208 | LCSC
28 | 1 | pour_le_waveshare-2.9\"-G | E-INK | FPC-SMD_24P-P0.50_FPC-05F-24PH20 |  | pour_le_waveshare-2.9\"-G | XUNPU(讯普) | C2856805 | LCSC
29 | 1 | 1uH | L1 | IND-SMD_L4.0-W4.0_ANR4012 | 1uH | ANR4012T1R0N | APV(爱普微) | C7497060 | LCSC
30 | 1 | 68uH | L3 | IND-SMD_L7.1-W6.6_H5.0 | 68uH | PSPMAA0605H-680M-IGF | PROD(谱罗德) | C2983094 | LCSC
31 | 1 | MPZ2012S601AT000 | L2 | L0805 |  | MPZ2012S601AT000 | TDK | C21519 | LCSC
32 | 1 | LD_MAX98357_Module | M1 | LD:MAX98357_Module | MAX98357
33 | 3 | YLED0805Y | PORT-1,PORT-2,PORT-3 | LED0805-RD_YELLOW |  | YLED0805Y | YONGYUTAI(永裕泰) | C20608785 | LCSC
34 | 1 | WS2812B-2020 | LED16 | LED-SMD_4P-L2.0-W2.0-TL_WS2812B-2020 |  | WS2812B-2020 | worldsemi | C965555 | LCSC
35 | 1 | LAN8720AI-CP | PHY | QFN-24_L4.0-W4.0-P0.50-BL-EP2.6 |  | LAN8720AI-CP | MICROCHIP(美国微芯) | C633282 | LCSC
36 | 1 | 0Ω | R32 | R0402 | 0Ω | FRC0402P000 TS | FOJAN(富捷) | C2906877 | LCSC
37 | 1 | 1.5kΩ | R41 | R0603 | 1.5kΩ | FRC0603F1501TS | FOJAN(富捷) | C2930050 | LCSC
38 | 2 | 2.2kΩ | P-SCL,P-SDA | R0603 | 2.2kΩ | FRC0603F2201TS | FOJAN(富捷) | C2907005 | LCSC
39 | 1 | 2.7kΩ | R19 | R0603 | 2.7kΩ | FRC0603F2701TS | FOJAN(富捷) | C2907008 | LCSC
40 | 5 | 10kΩ | R13,R14,R15,R16,R21 | R0603 | 10kΩ | FRC0603F1002TS | FOJAN(富捷) | C2906982 | LCSC
41 | 1 | 10kΩ | R22 | R0603 | 10kΩ | FRC0603J103 TS | FOJAN(富捷) | C2930027 | LCSC
42 | 9 | 10kΩ | R8,R9,R10,R11,R12,R26,R27,R28,R54 | R0603 | 10kΩ | RC0603FR-0710KL | YAGEO(国巨) | C98220 | LCSC
43 | 1 | 12.1kΩ | R7 | R0603 | 12.1kΩ | FRC0603F1212TS | FOJAN(富捷) | C2930059 | LCSC
44 | 22 | 22Ω | R37,R38,R39,R40,R42,R43,R44,R46,R47,R48,R49,R50,R51,R52,R53,R55,R56,R57,R58,R59,R60,R61 | R0603 | 22Ω | FRC0603J220 TS | FOJAN(富捷) | C2907129 | LCSC
45 | 1 | 44.2kΩ | R31 | R0603 | 44.2kΩ | 0603WAF4422T5E | UNI-ROYAL(厚声) | C23056 | LCSC
46 | 4 | 49.9Ω | R3,R4,R5,R6 | R0603 | 49.9Ω | FRC0603F49R9TS | FOJAN(富捷) | C2930110 | LCSC
47 | 4 | 75Ω | R33,R34,R35,R36 | R0603 | 75Ω | 0603WAF750JT5E | UNI-ROYAL(厚声) | C4275 | LCSC
48 | 3 | 100kΩ | R23,R29,R45 | R0603 | 100kΩ | FRC0603J104 TS | FOJAN(富捷) | C2907088 | LCSC
49 | 1 | 100Ω | R20 | R0603 | 100Ω | FRC0603F1000TS | FOJAN(富捷) | C2906981 | LCSC
50 | 1 | 200kΩ | R30 | R0603 | 200kΩ | FRC0603F2003TS | FOJAN(富捷) | C2907009 | LCSC
51 | 1 | 220Ω | R24 | R0603 | 220Ω | FRC0603J221 TS | FOJAN(富捷) | C2907127 | LCSC
52 | 1 | 270Ω | R25 | R0603 | 270Ω | 0603WAF2700T5E | UNI-ROYAL(厚声) | C22966 | LCSC
53 | 4 | 1kΩ | R-RX1,R-RX2,R-TX1,R-TX2 | R0603_1 | 1kΩ | 0603WAF1001T5E | UNI-ROYAL(厚声) | C21190 | LCSC
54 | 2 | 5.1kΩ | R1,R2 | R0603_1 | 5.1kΩ | 0603WAF5101T5E | UNI-ROYAL(厚声) | C23186 | LCSC
55 | 2 | 260Ω | R17,R18 | R0805 | 260Ω | Y1624260R000T9W | VISHAY(威世) | C4343831 | LCSC
56 | 1 | Radxa_rCore_RK3308 | SBC | Radxa_rCore_RK3308-bon_1
57 | 1 | R-RJ45R08P-C000 | RJ45 | RJ45-TH_R-RJ45R08P-C000 |  | R-RJ45R08P-C000 | Ckmtw(灿科盟) | C386757 | LCSC
58 | 1 | PCF2129T/2,518 | RTC | SO-16_L10.3-W7.5-P1.27-LS10.3-BL |  | PCF2129T/2,518 | NXP(恩智浦) | C2651522 | LCSC
59 | 3 | MBR0530 | U21,U22,U23 | SOD-123_L2.7-W1.6-LS3.7-RD-1 |  | MBR0530 | TWGMC(迪嘉) | C5204746 | LCSC
60 | 2 | BSS138 | Q2,Q3 | SOT-23-3_L3.0-W1.7-P0.95-LS2.9-BR |  | BSS138 | HT(金誉) | C27140738 | LCSC
61 | 2 | 74AHCT1G125GV | LEVEL_SHIFFTER-1,LEVEL_SHIFFTER-2 | SOT-23-5_L3.0-W1.7-P0.95-LS2.8-BL |  | 74AHCT1G125GV | MDD(辰达半导体) | C52140417 | LCSC
62 | 1 | SI1308EDL | Q1 | SOT-323-3_L2.0-W1.3-P1.30-LS2.1-BR |  | SI1308EDL | TECH PUBLIC(台舟) | C7603347 | LCSC
63 | 1 | FE1.1S-BSOP28BCN | USB_SWITCH | SSOP-28_L9.9-W3.9-P0.635-LS6.0-BL-1 |  | FE1.1S-BSOP28BCN | TERMINUS | C9359 | LCSC
64 | 4 | HX 3x6x2.5A-2.5N | ESP_BOOT,ESP_RST,MASKROM,RST_CMPT | SW-SMD_HX-TS-1101-C-W |  | HX 3x6x2.5A-2.5N | hanxia(韩下) | C36498960 | LCSC
65 | 18 | Test-Point | 3V3,5V,BAT+,FLASH_CS0N,FLASH_RDY,GND,GPIO0_A1,REG_OUT,RSC_3V3,SCL,SDA,TP1,TP2,TP3,TP4,TP5,TP6,VCC_1.8 | Test-Point-0.5mm
66 | 1 | TF-025 | SLOT2 | TF-SMD_TF-025 |  | TF-025 | Hanbo Electronic | C5310489 | LCSC
67 | 1 | TF PUSH | SLOT1 | TF-SMD_TF-PUSH |  | TF PUSH | SHOU HAN(首韩) | C393941 | LCSC
68 | 1 | IC-new_PMIC-MP2161_'GJ' | Buck_1 | TSOT23-8
69 | 2 | MMBT3904 | Q4,Q5 | TSOT-23-3_L3.0-W1.6-P0.95-LS2.8-BR |  | MMBT3904 | Huixin(慧芯) | C49435601 | LCSC
70 | 1 | UC.01.51-11-0017,typec | USB-C2 | TYPE-C-SMD_UC.01.51-11-0017 |  | UC.01.51-11-0017,typec |  | C9900066641 | LCSC
71 | 1 | UE27AC54100 | USB_HOST | USB-A-TH_UE27AC54100 |  | UE27AC54100 | Amphenol | C464564 | LCSC
72 | 1 | 2.4GHz | ESP32 | WIFIM-SMD_38P-L19.2-W18.0-P1.27 | 2.4GHz | ESP32-WROOM-32U-N4 | ESPRESSIF(乐鑫) | C328062 | LCSC
73 | 1 | HX1188NL | FILT | XFMR-SMD_16P-L12.7-W7.1-P1.27-LS9.4-BL |  | HX1188NL | PULSE(普思) | C6176011 | LCSC

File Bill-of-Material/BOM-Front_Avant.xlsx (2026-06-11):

No. | Quantity | Comment | Designator | Footprint | Value | Manufacturer Part | Manufacturer | Supplier Part | Supplier
1 | 1 | 4.7uF | C10 | C0603 | 4.7uF | CL10A475KP8NNNC | SAMSUNG(三星) | C1705 | LCSC
2 | 1 | 100nF | C9 | C0603 | 100nF | CC0603KRX7R9BB104 | YAGEO(国巨) | C14663 | LCSC
3 | 1 | FPC-05F-6PH20 | FPC1 | FPC-SMD_6P-P0.50_XUNPU_FPC-05F-6PH20 |  | FPC-05F-6PH20 | XUNPU(讯普) | C2856796 | LCSC
4 | 1 | VL53L0CXV0DH/1 | U1 | OPTO-SMD_12P_VL53L0CXV0DH-1 |  | VL53L0CXV0DH/1 | ST(意法半导体) | C91199 | LCSC
5 | 1 | 10kΩ | XSHT_PUP | R0603 | 10kΩ | FRC0603J103 TS | FOJAN(富捷) | C2930027 | LCSC

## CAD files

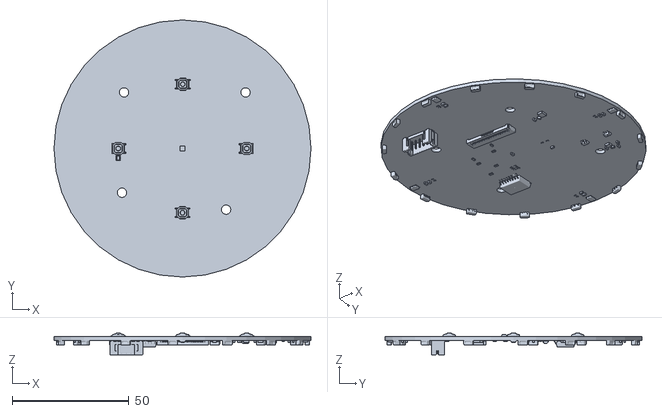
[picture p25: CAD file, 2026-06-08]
3D_Files/Top-PCB\Haut.stl
110.0 x 110.0 x 9.35

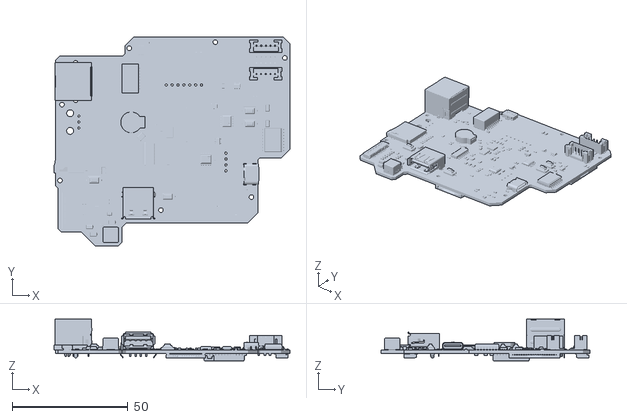
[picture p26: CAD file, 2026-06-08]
3D_Files/Brain\Cerveau.stl
101.8 x 90.1 x 18.1

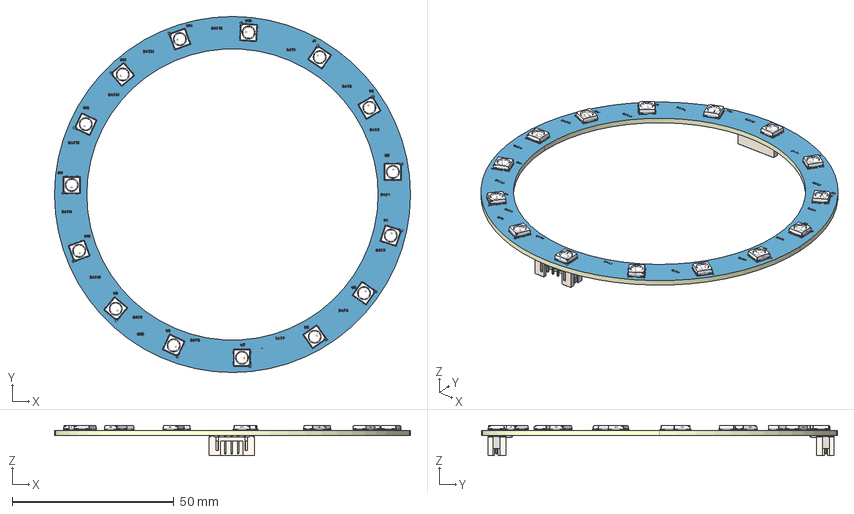
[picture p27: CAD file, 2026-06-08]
3D_Files/Contour.step
110.0 x 110.0 x 9.40 mm
Board~u2L1
TopCopper~u2L1
BottomCopper~u2L1
TopSilkscreen~u2L1 x 165
BottomSilkscreen~u2L1 x 33
TopFpcStiffener~u2L1
BottomFpcStiffener~u2L1
LED-SMD_4P-L5.0-W5.0-LS5.4-TL-1~LED-SMD_4P-L5.0-W5.0-LS5.4-TL-1~u2L1 x 15
CONN-SMD_5P-P2.00_B6B-PH-SM4-TB-LF-SN~CONN-SMD_5P-P2.00_ B6B-PH-SM4-TB-LF-SN~u2L1 x 2

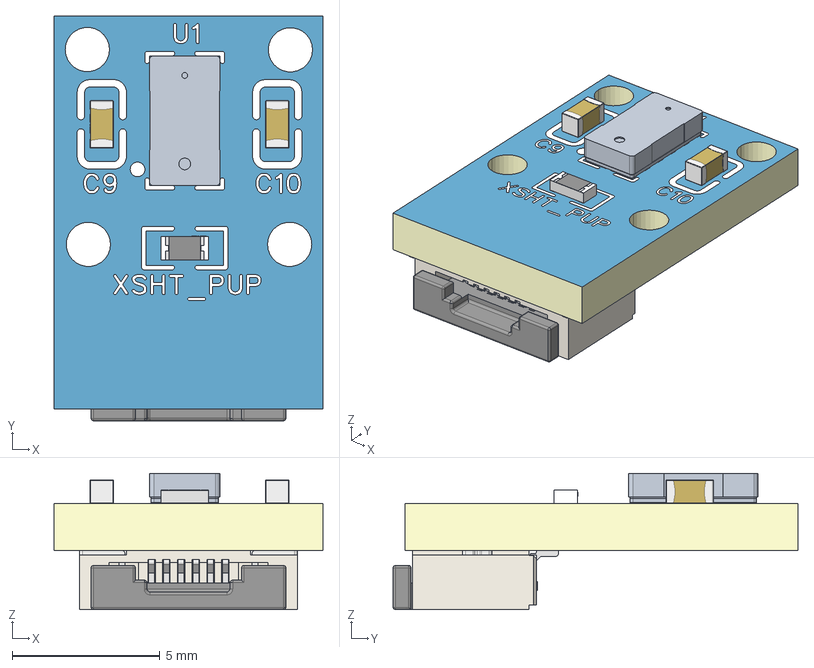
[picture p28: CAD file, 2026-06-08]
3D_Files/Front-PCB\Face.step
9.12 x 13.7 x 4.62 mm
Board~X3gs
TopCopper~X3gs
BottomCopper~X3gs
TopSilkscreen~X3gs x 28
BottomSilkscreen~X3gs x 19
TopFpcStiffener~X3gs
BottomFpcStiffener~X3gs
C0603~C0603_L1.6-W0.8-H0.8~X3gs x 2
FPC-SMD_6P-P0.50_XUNPU_FPC-05F-6PH20~FPC-SMD_6P-P0.50_XUNPU_ FPC-05F-6PH20~X3gs
OPTO-SMD_12P_VL53L0CXV0DH-1~OPTO-SMD_12P_VL53L0CXV0DH-1~X3gs
R0603~R0603~X3gs

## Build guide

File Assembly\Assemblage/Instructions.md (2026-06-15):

This file contains instructions on how to put together this device, describes what the different connectors that are circled and explains how to correct the mistaque mentionned before.

Ce fichier contien des instructions sur l'assemblage de cet apareil, décris les différents connecteurs entourés et montre comment corriger l'erreur évoqué sur la première page.

Brain_front_connectors / Connecteurs_dessus_cerveau.
Brain front connectors

- The connector circled in violet is to connect the Front_PCB. / Le connecteur entouré en violet sert à connecter le Circuit_face.
- The connector circled in black is to connect the MAX98357A module (based on ADAFRUIT's design). / Le connecteur entouré en noir sert à connecter le module MAX98357A (basé sur le design d'ADAFRUIT).
- The connector circled in light-blue is to connect the Bottom_PCB (Power). / Le premier connecteur entouré en cyan sert à connecter le Circuit_Bas (Alim).
- The connector circled in magenta is to connect to the Contour_PCB (Data and Power). / Le connecteur entouré en magenta sert à connecter le pcb du contour (Données et Alim).
- The usb-c connector circled in blue is to debug and programm the device before it's assembled. / Le connecteur usb-c entouré en bleu sert à débeugué et programmer l'apareil avant d'être assemblé. 
- The connector circled in pink is tied to the linux brain and act as a host usb port. It's made for peripherals and accessories. / Le connecteur entouré en rose est rataché au cerveau liux et se comporte comme un port usb hôte. Il sert à connecter des périphériques et accessoires.
- The connector circled in yellow is the primary micro sd card slot and cannot be used simultaneously with the second one. / Le connecteur entourré en jaune est le slot de carte micro sd principal et ne peut pas être utilisé simultanément avec le second.
- The connector circled in red is to connect an SPDIF/TOSLINK fiber cable for outpouting audio. / Le connecteur entouré en rouge sert à connecter un cable fibre SPDIF/TOSLINK pour faire sortir l'audio.
- The connector circled in turquoise is to connect an ethernet cable. / Le connecteur entouré en turquoise sert à conncter un cable ethernet.

Brain_bottom_connectors / Connecteurs_dessous_cerveau.
Brain bottom connectors

- The connector circled in Green is to connect the top_pcb. / Le connecteur entouré en vert sert à connecter le circuit du dessus.
- The connector circled in violet is to connect an optionnal rotary encoder. / Le connecteur entouré en violet set à connecter un encodeur rotatif optionnel.
- The connector circled in red is to connect the bottom_pcb. / Le connecteur entouré en rouge sert à connecter le circuit du bas.
- The connector circledd in orange is to connect the 3,3V regulator (based on ADAFRUIT's design). / Le connecteur entouré en orange sert à connecter le régulateur 3,3V (basé sur le design d'ADAFRUIT). 
- The connector circled in yellow is the second micro sd card slot and cannot be used alongside the first one. / Le connecteur entouré en jaune est le second slot micro sd et ne peut pas être utilisé avec le premier simultanément.
- The cyan and blue lines represents the two wires to solder and fix the i²c bus and are mandatory. / Les lignes cyan et bleu représentes les deux fils à souder pour réparer le  bus i²c et obligatoires.

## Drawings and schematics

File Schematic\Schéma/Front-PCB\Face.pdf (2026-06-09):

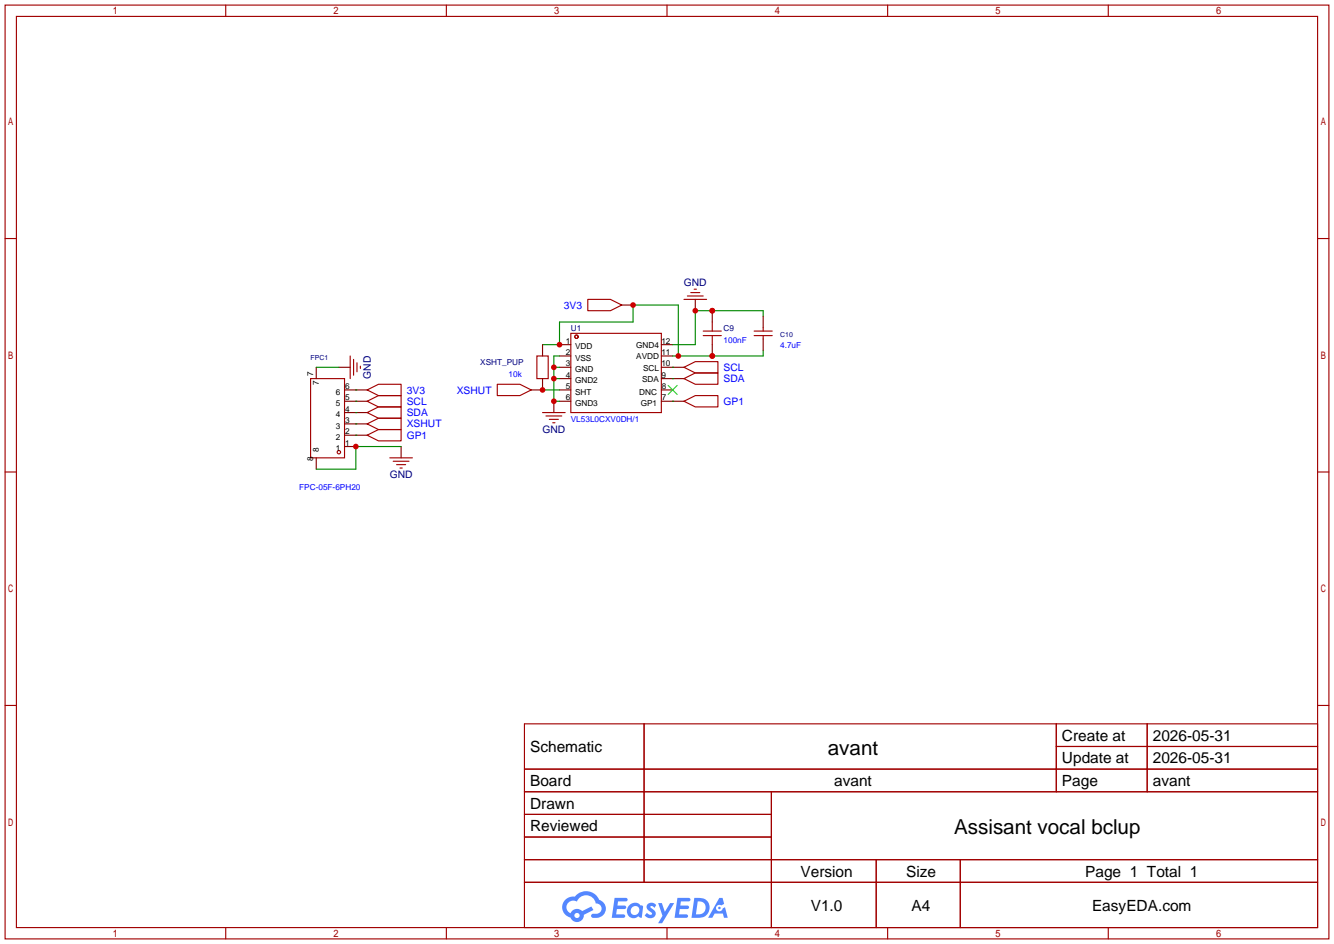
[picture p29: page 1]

Schematic | avant | Create at | 2026-05-31

Update at | 2026-05-31

Board | avant | Page | avant
Drawn | | Assisant vocal bclup
Reviewed

Version | Size | Page 1 Total 1
V1.0 | A4 | EasyEDA.com

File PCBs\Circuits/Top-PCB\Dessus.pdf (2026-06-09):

LIGHT1

LED16

SW1

SW2

SW3

SW4

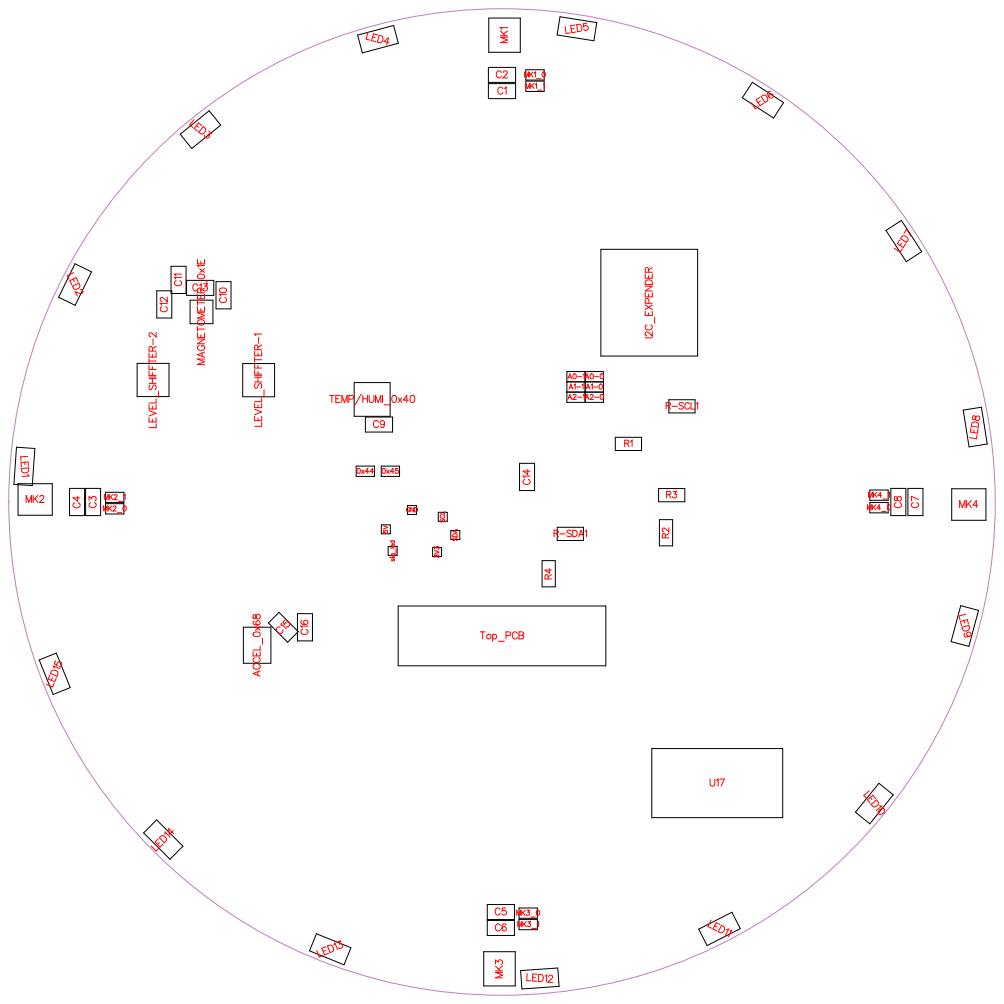
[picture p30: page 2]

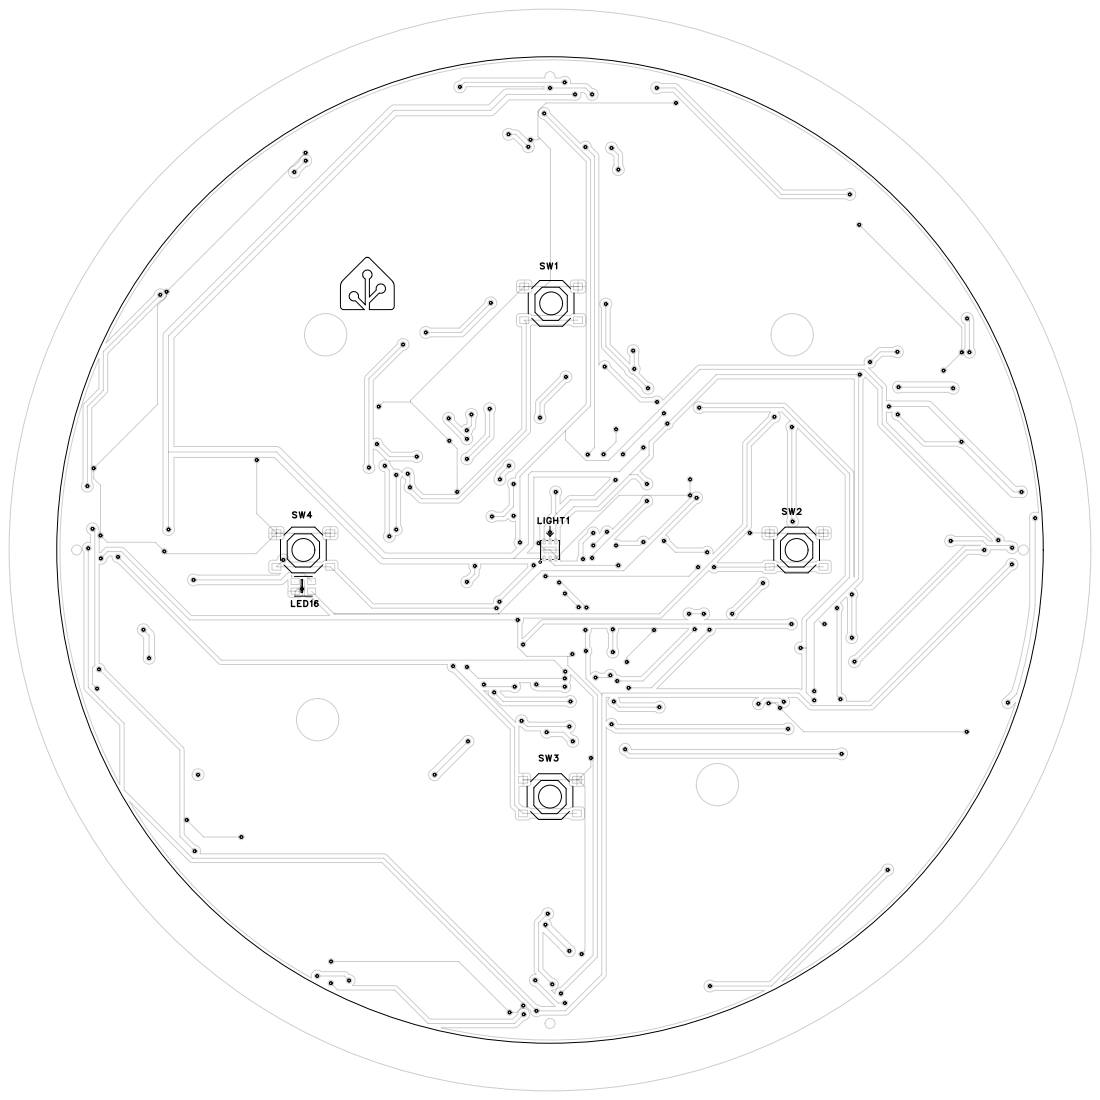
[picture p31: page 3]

# @TWNINKLY09

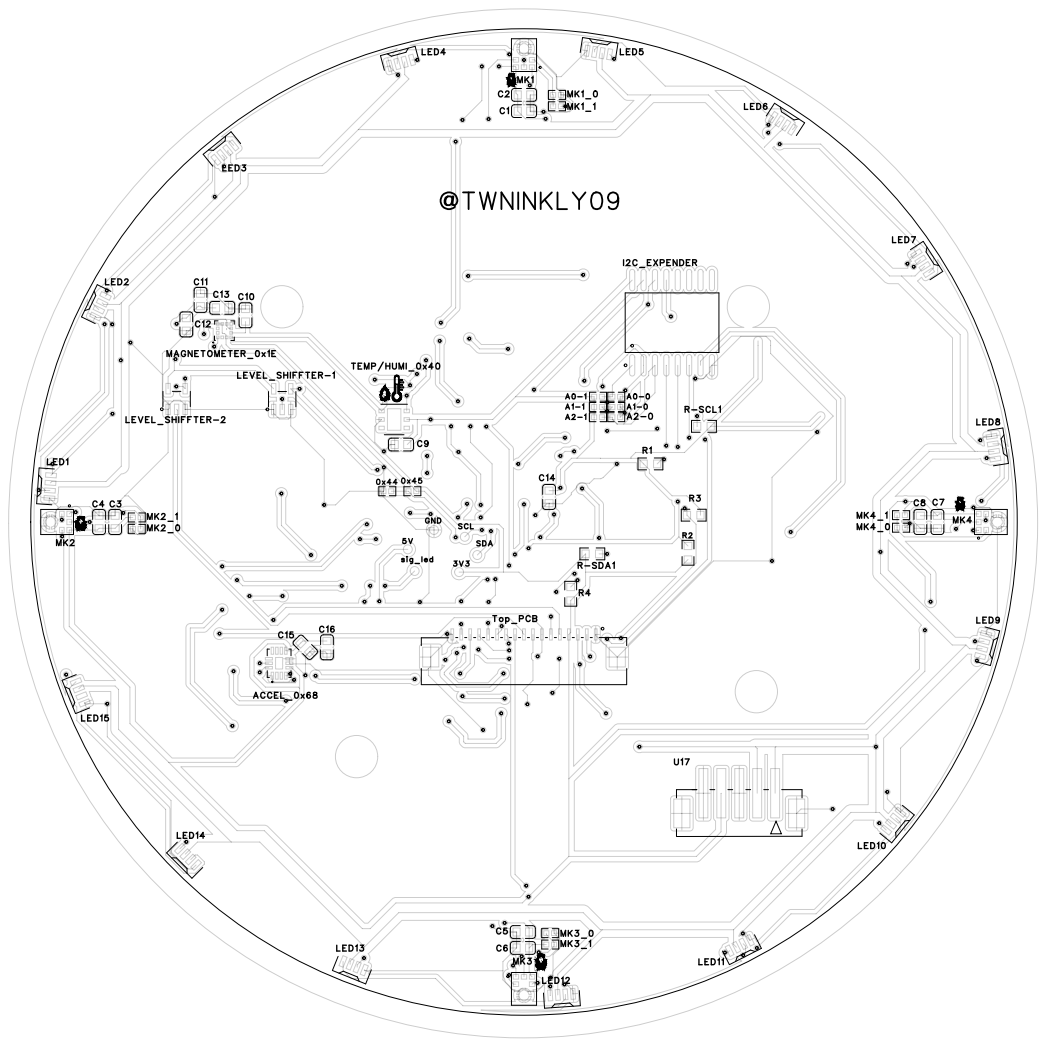
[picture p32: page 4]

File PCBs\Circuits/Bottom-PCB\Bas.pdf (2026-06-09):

## SDA U³

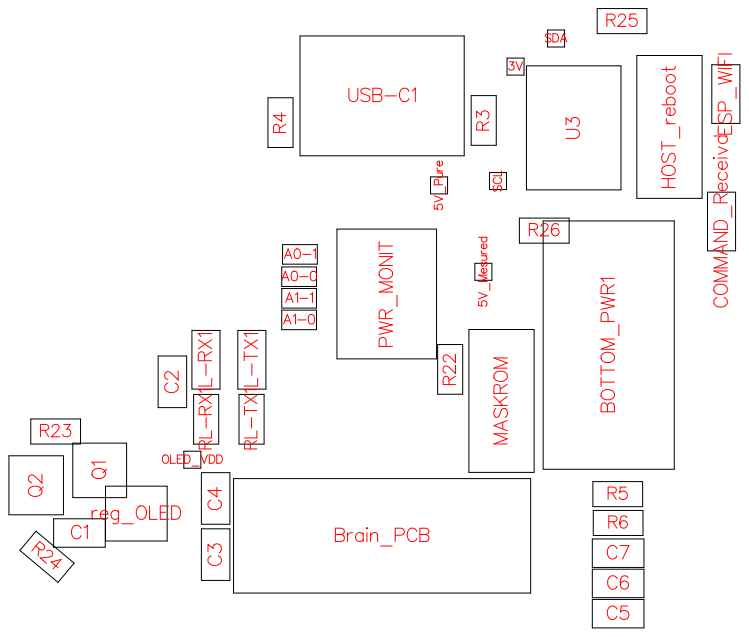
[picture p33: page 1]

OLED

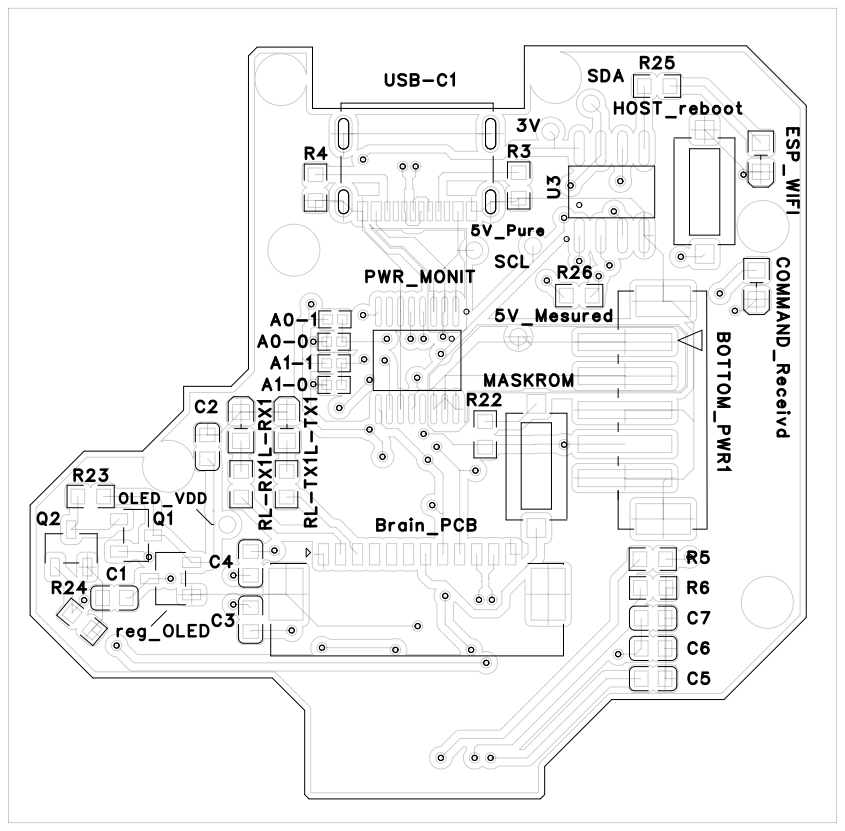
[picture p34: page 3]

MASKROM
R22

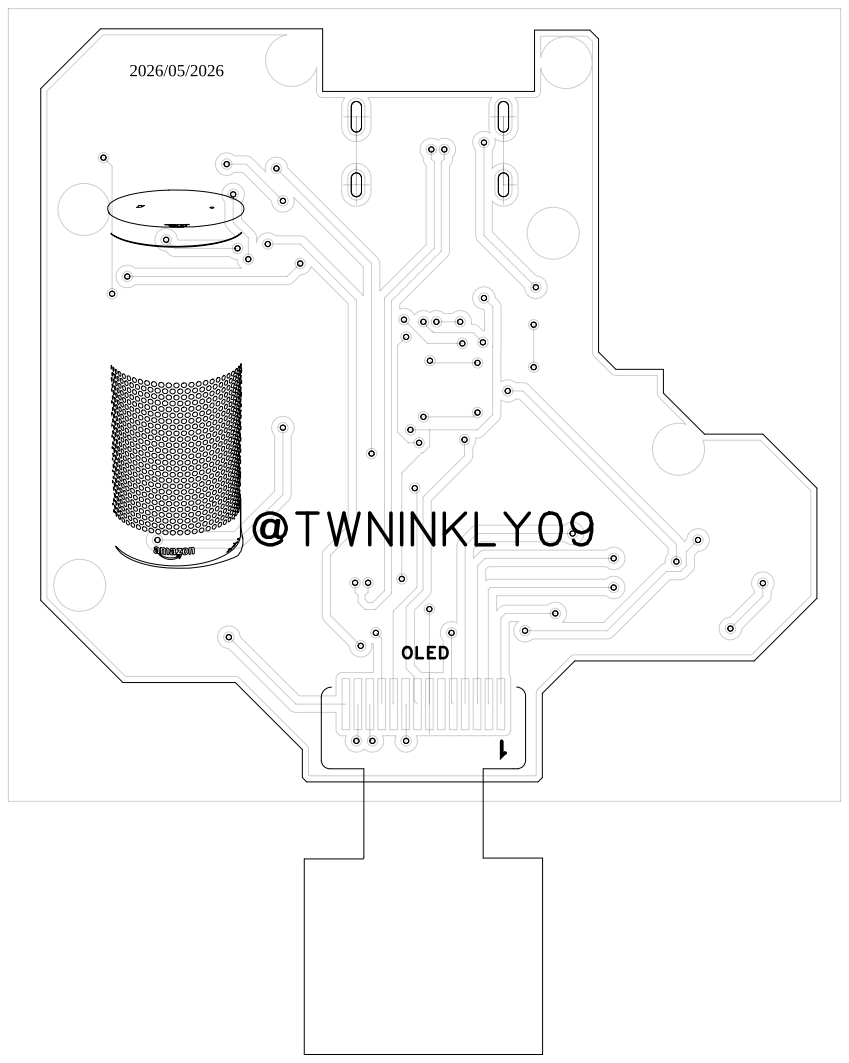
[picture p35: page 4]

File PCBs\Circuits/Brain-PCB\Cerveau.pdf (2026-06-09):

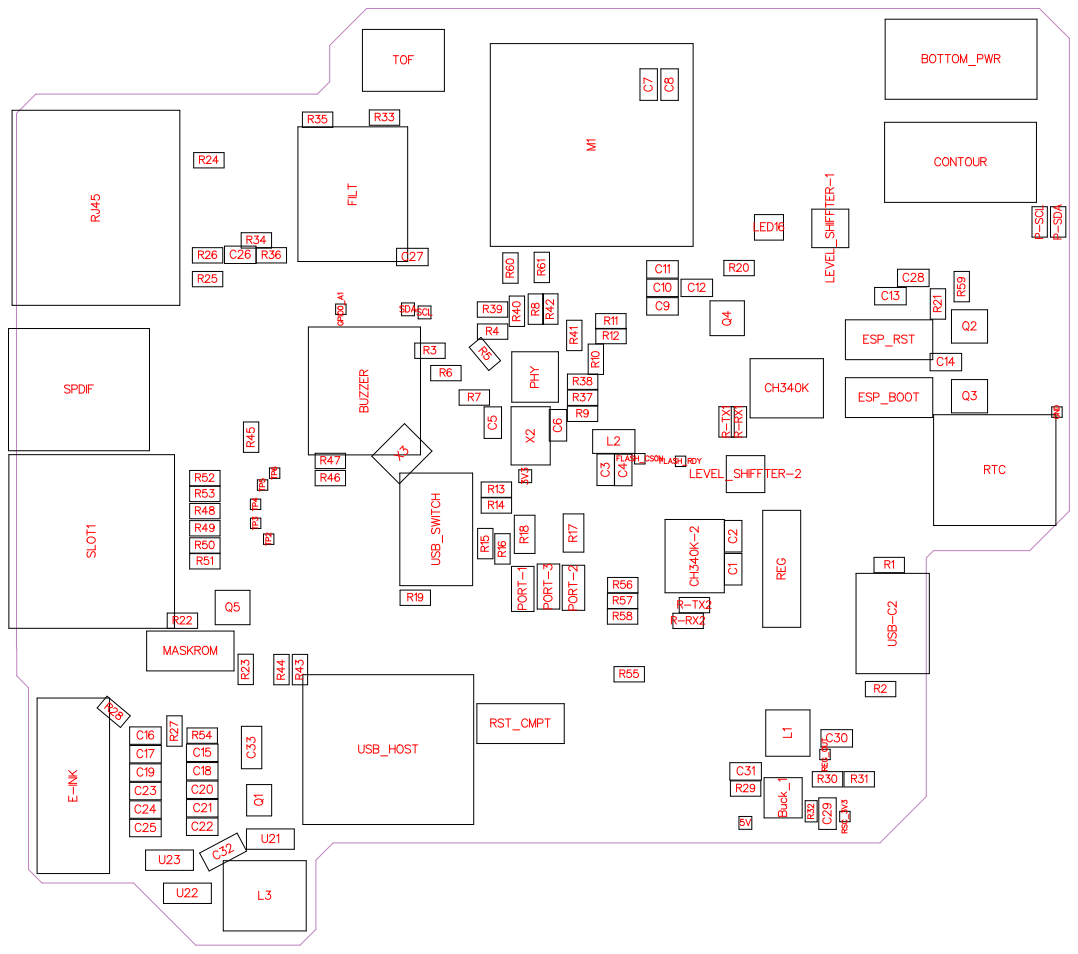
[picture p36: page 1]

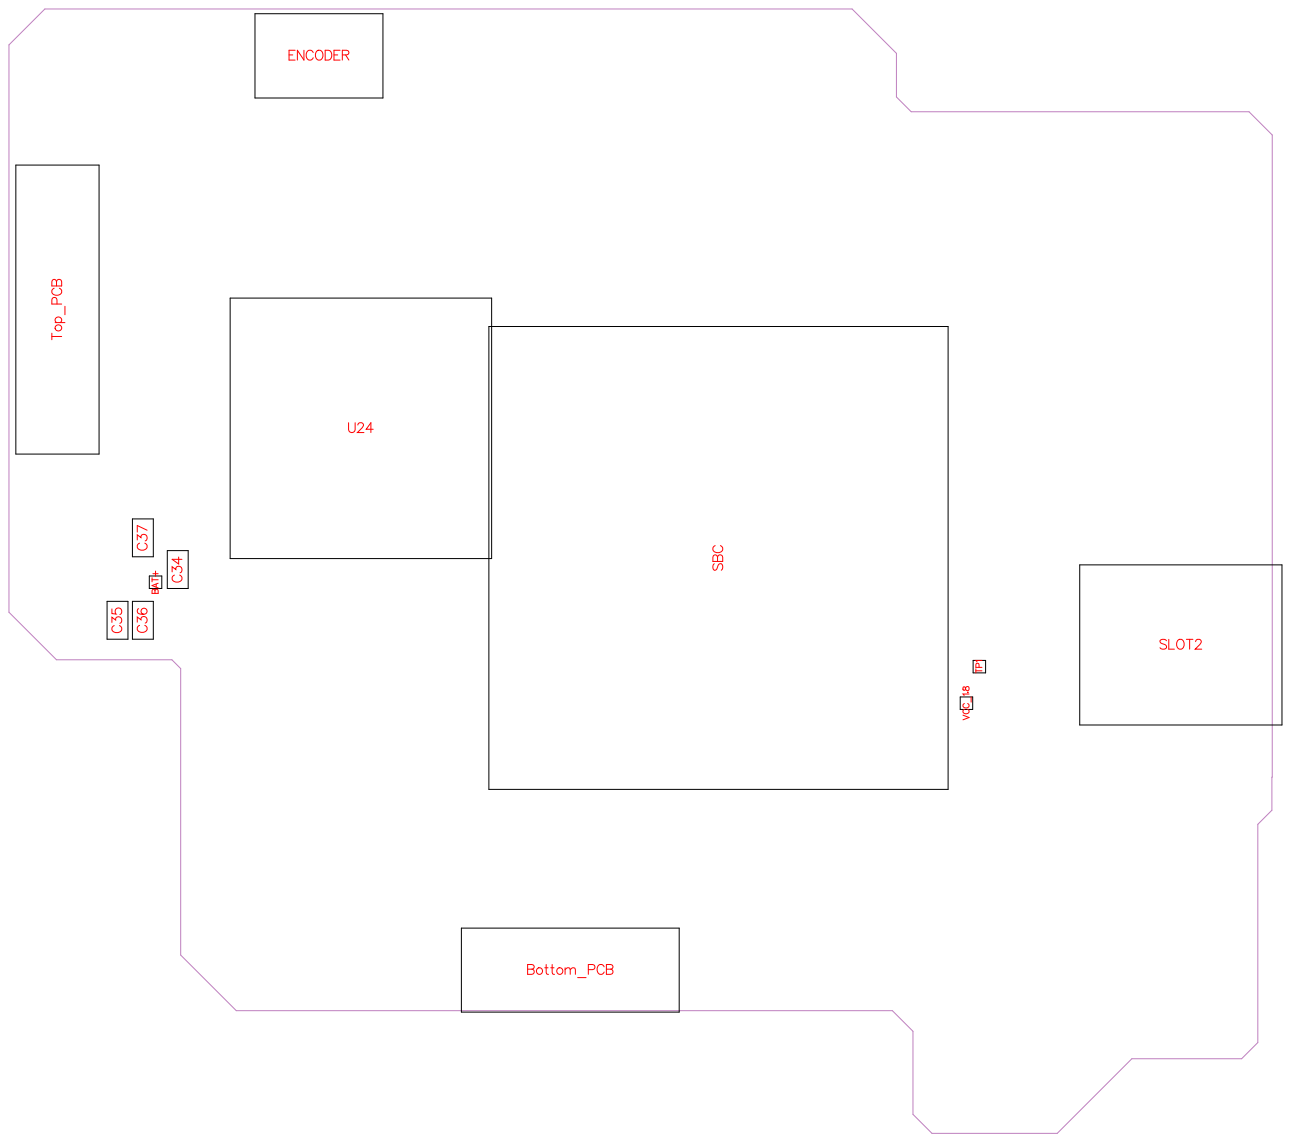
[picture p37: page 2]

M1

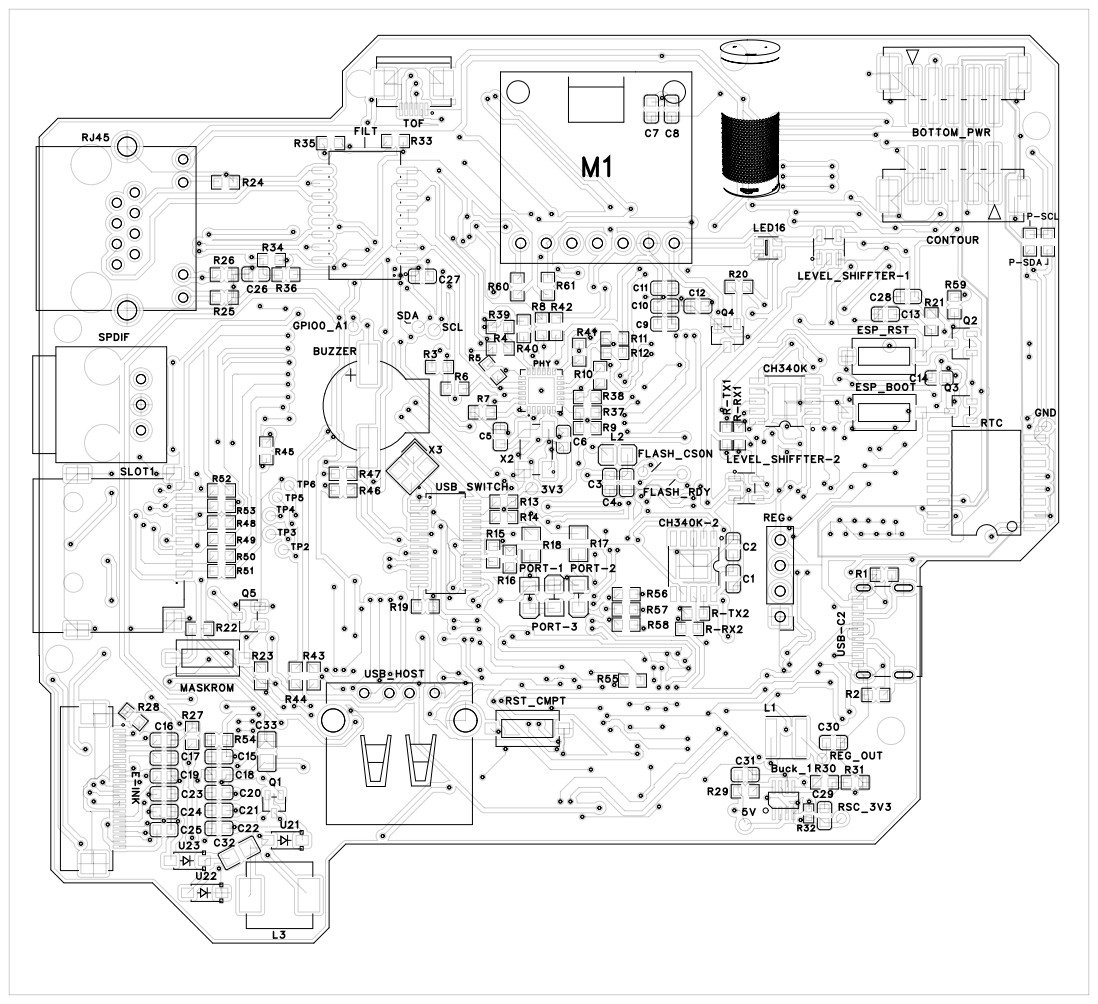
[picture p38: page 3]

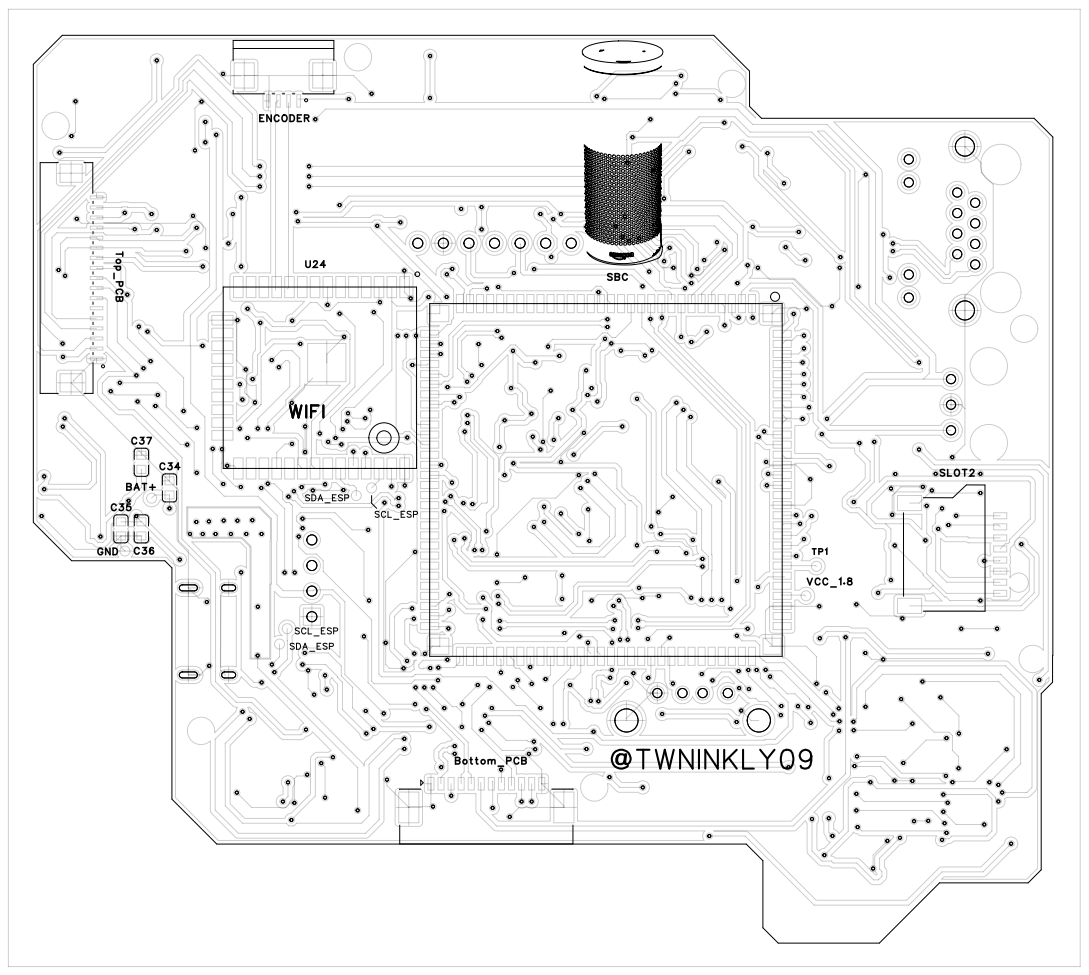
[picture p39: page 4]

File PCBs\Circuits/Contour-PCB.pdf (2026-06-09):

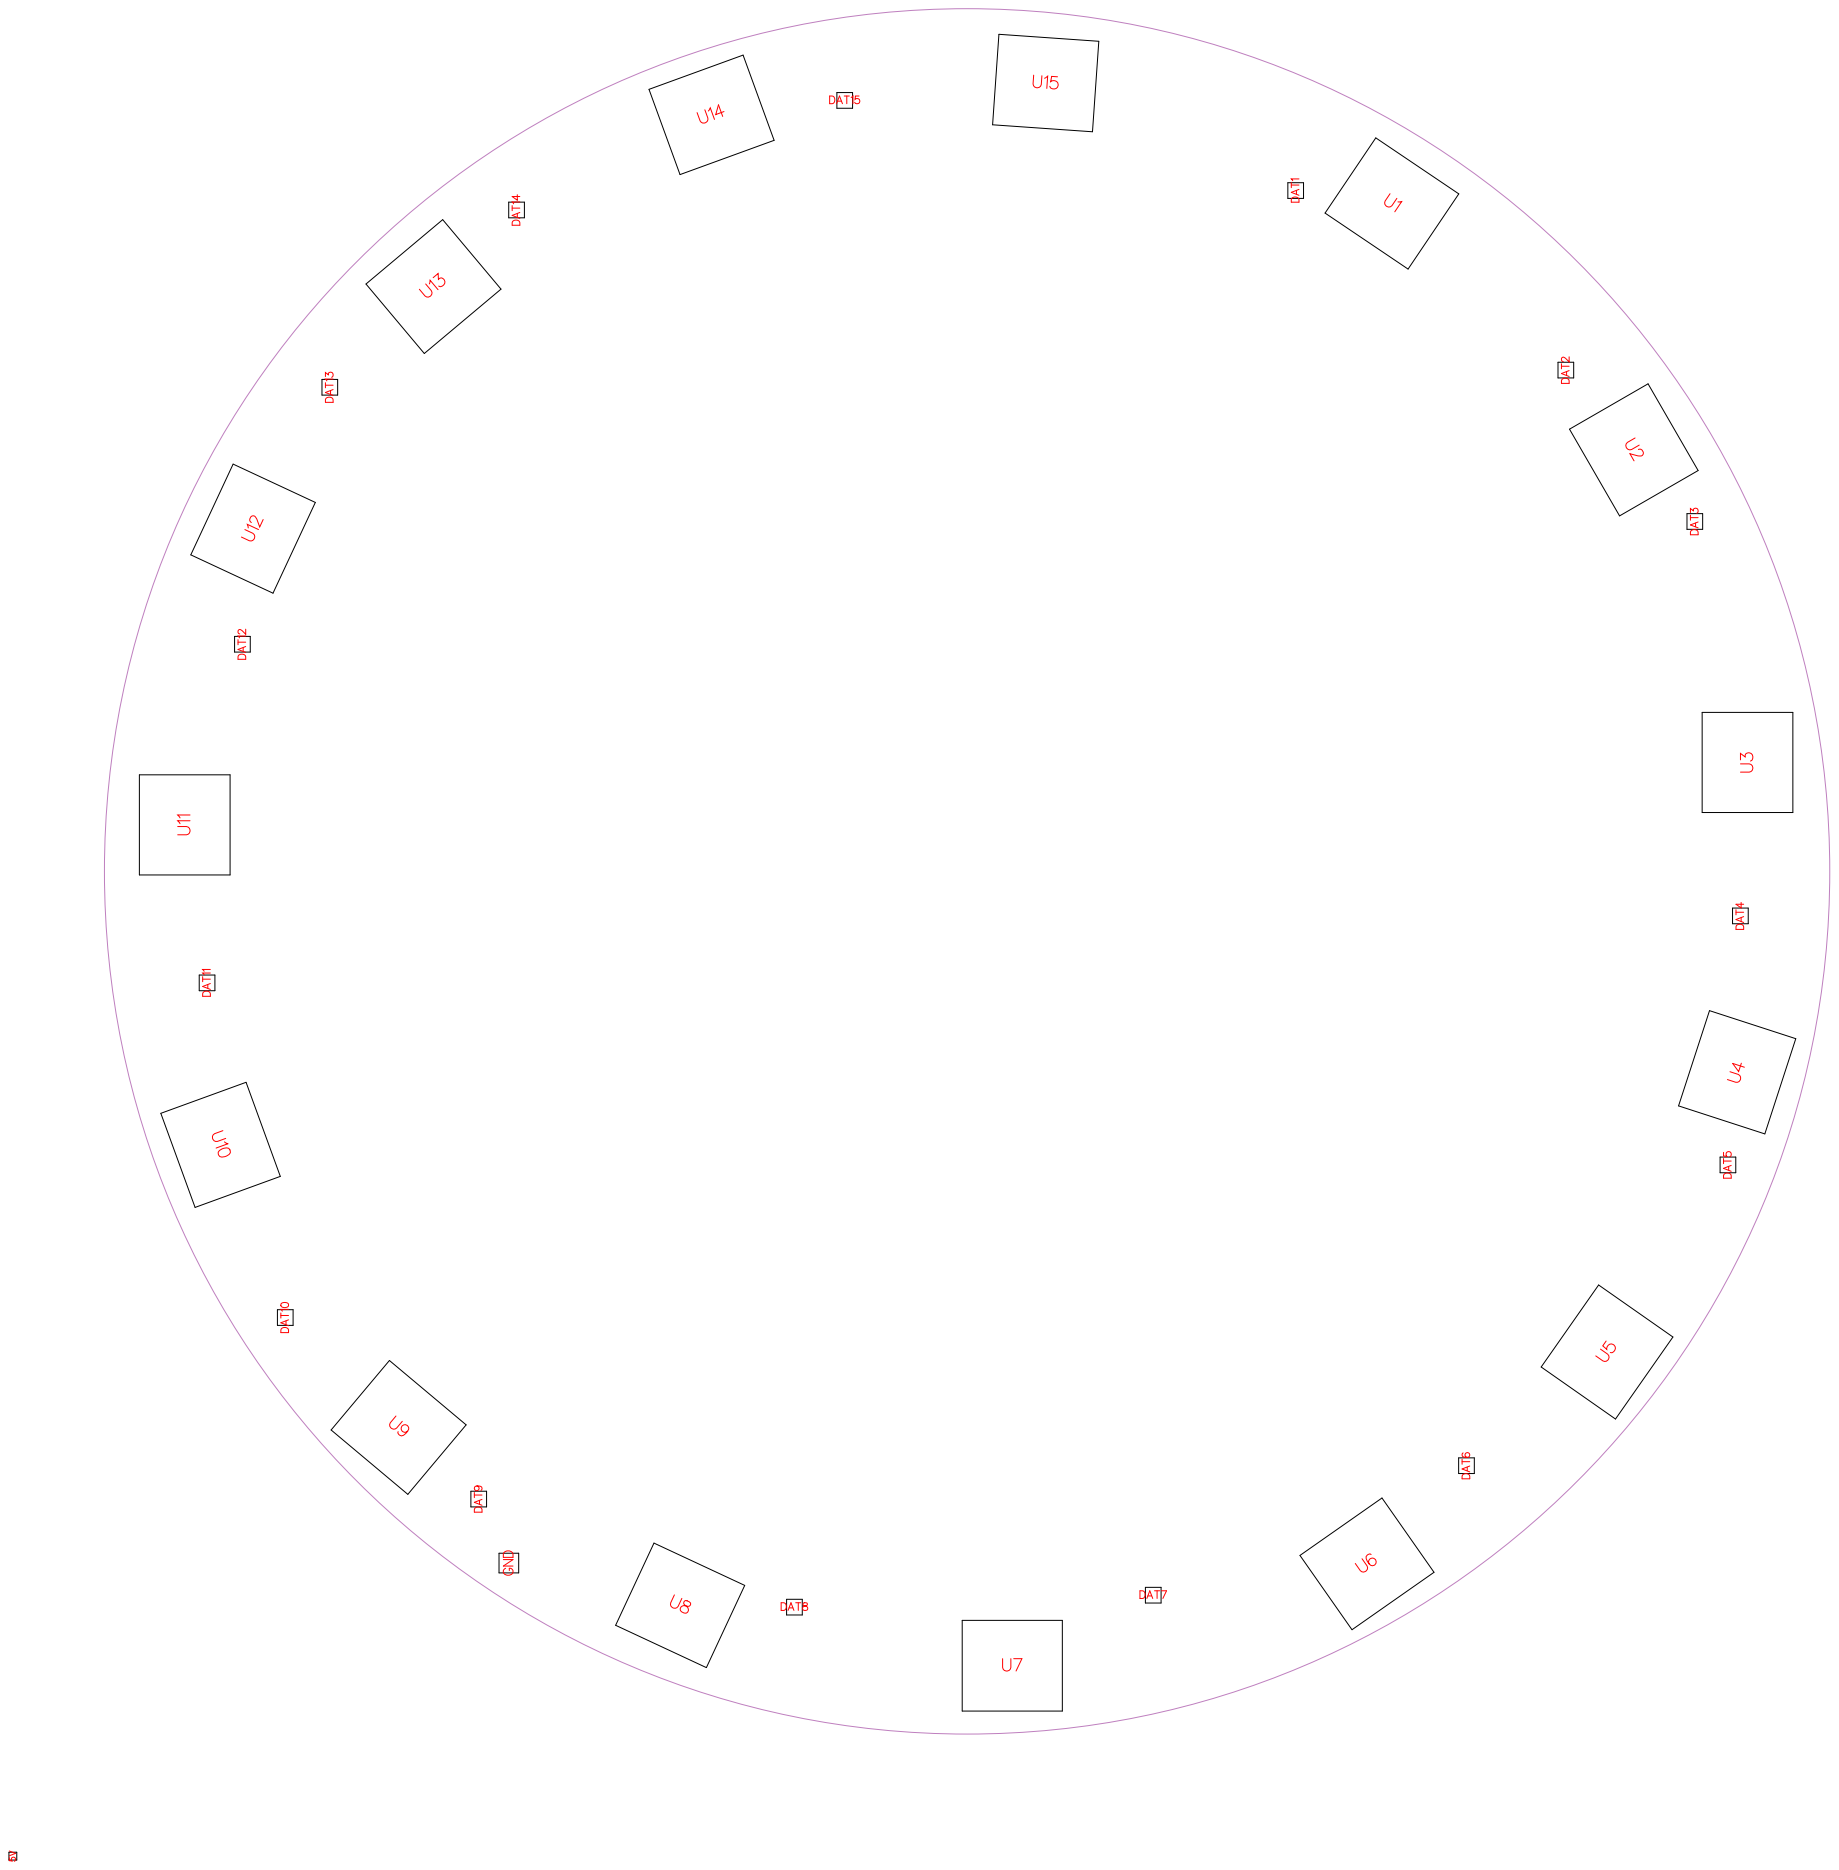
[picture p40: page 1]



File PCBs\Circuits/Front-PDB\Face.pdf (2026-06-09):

FPC1



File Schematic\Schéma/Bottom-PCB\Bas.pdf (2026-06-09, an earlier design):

# VS 10 GND 11 VBUS 12 NC 13 IN- 14 IN- 15 IN- 16


Boutons et Leds d'activité

Schematic | Dessous | Create at | 2026-05-31

Update at | 2026-05-31

Board | Dessous | Page | P1
Drawn | | Assisant vocal bclup
Reviewed

Version | Size | Page 1 Total 1
V1.0 | A4 | EasyEDA.com

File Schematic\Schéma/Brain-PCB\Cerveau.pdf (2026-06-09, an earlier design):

# Connectors_PCB

# Status_LED


ETH_FILTER
CMT 10 RX+ 11 12 12 13 13 TX- 14 CMT 15 TX+ 16

AUDIO DIGITAL I2S/PDM/SPDIF

Update at | 2026-06-08

Board | Cerveau | Page | P1
Drawn | | Assisant vocal bclup
Reviewed

Version | Size | Page 1 Total 1
V1.0 | A4 | EasyEDA.com

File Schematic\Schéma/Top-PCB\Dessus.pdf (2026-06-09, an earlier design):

# 4.7k GND

R1


Schematic | Dessus | Create at | 2026-05-31

Update at | 2026-06-02

Board | Dessus | Page | Haut
Drawn | | Assisant vocal bclup
Reviewed

Version | Size | Page 1 Total 1
V1.0 | A4 | EasyEDA.com

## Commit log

2026-06-08 Add description for PCB images folder
2026-06-08 Update README with silkscreen note and French text
    Added a note regarding the silkscreen status and updated the French translation.
2026-06-09 Create README.md for Datasheet
    Add README file for PCB design and component information.
2026-06-09 Add PDF descriptions for schematics
    Add descriptions for schematic PDFs in English and French.
2026-06-09 Add PCB image to README
    Added an image of the PCB to the README.
2026-06-09 Create Instructions.md for device assembly
    Added instructions for device assembly and connector explanation.
2026-06-09 Change PCB images from JPG to PNG format
    Updated image file formats from .jpg to .png for better quality.
2026-06-09 Fix image paths for brain front and bottom connectors
    Updated image paths for brain connectors in Instructions.md.
2026-06-09 Revise connector instructions in Instructions.md
    Updated connector descriptions for clarity and added new connections.
2026-06-11 Update README with new animation for ESP32 error
    Added a new animation demonstration for ESP32 error handling.
2026-06-11 Create readme.md for component list
    Add bilingual readme for Bill-of-Material folder
2026-06-19 Document components connected to Radxa module
    Added detailed information about components connected to the Radxa module, including descriptions for each PCB and their respective components.

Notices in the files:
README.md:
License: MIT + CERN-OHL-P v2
